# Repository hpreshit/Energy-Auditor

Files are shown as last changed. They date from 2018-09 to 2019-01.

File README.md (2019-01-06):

<p align="center">
 Energy Auditor Logo
</p>  

## Low Power Embedded Design Techniques Course Project - University of Colorado Boulder
## Team  
###  Gunj Manseta  |  Preshit Harlikar  
###  Aakash Kumar  |  Ashish Tak  |  Smitesh Modak  

## Project Idea  
We intend to build an Energy Auditing System through a combination of Bluetooth mesh
sensor nodes and a Gateway. The system will gather all the sensor node information and
send it to cloud for data analysis through Gateway.
Two Teams will collaborate to build this entire system. Our team will work on developing a
Bluetooth mesh network of wireless power meter sensor nodes that can clamp on to mains
line noninvasively. These nodes will report the measured power to the Gateway which will
be developed by the other team.

## What problem does the project solve?
Energy audit and conservation projects require measuring the existing power consumption
for the equipment under audit to create a baseline of the existing consumption. Electrical
circuits may not be isolated by the type of equipment in many buildings, this causes errors
in calculation of the power consumption of the equipment under audit, resulting in
erroneous calculation of the baseline, which in turns affects all other energy conservation
calculations. Setting up wired metering infrastructure for such temporary measurements
would be very tedious and labor intensive. Our project will help setup temporary metering
infrastructure that is not labor intensive to setup due to it being wireless and noninvasive.
  
## System Block Diagram
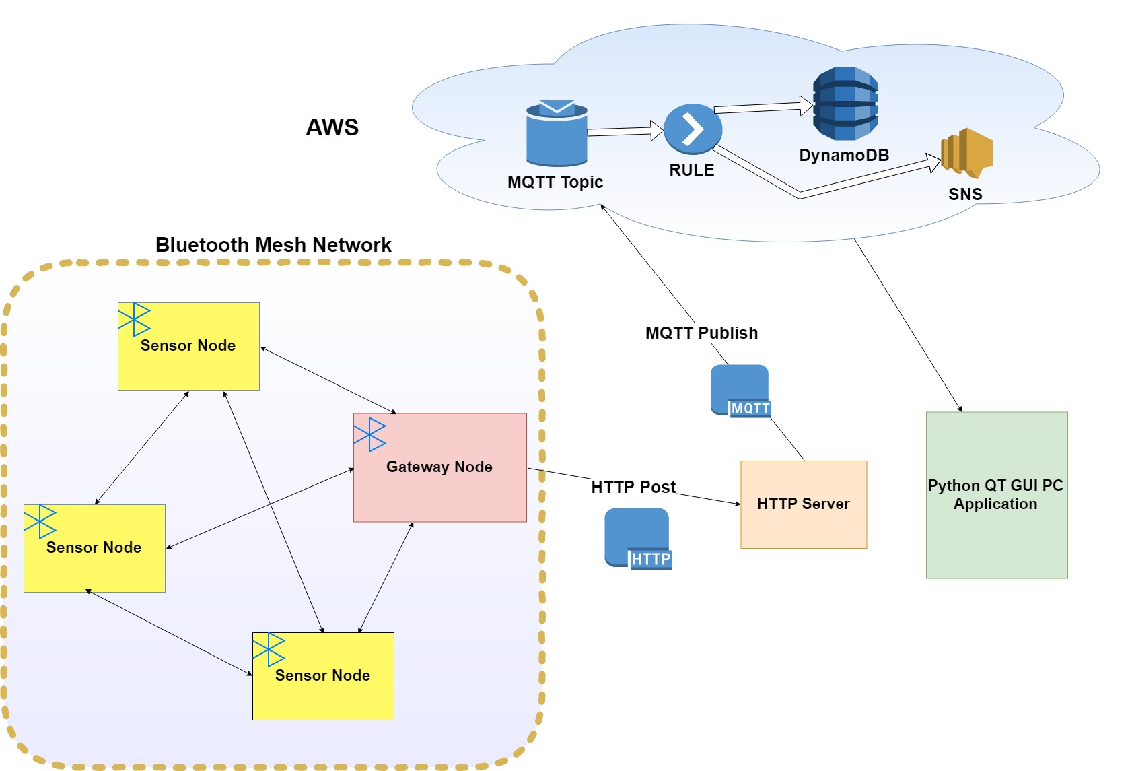
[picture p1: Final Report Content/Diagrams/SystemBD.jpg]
System Block Diagram


## Sensor Node Block Diagram
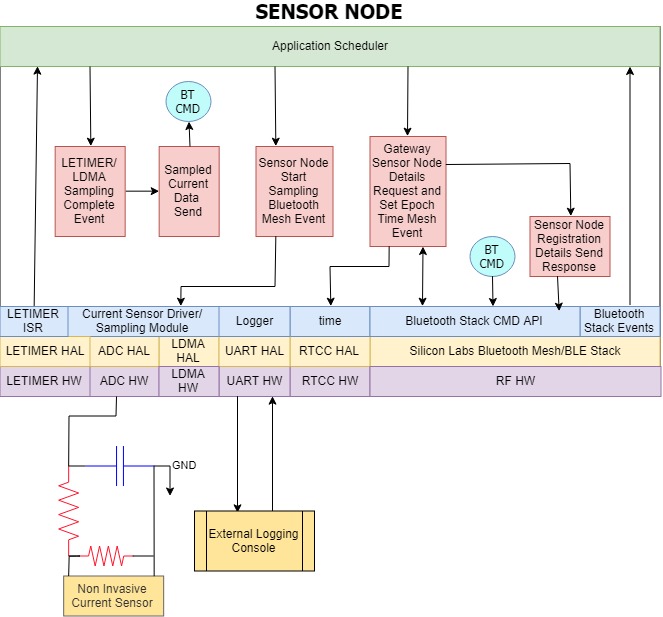
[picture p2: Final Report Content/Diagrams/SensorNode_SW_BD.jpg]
System Block Diagram


## Gateway Node Block Diagram
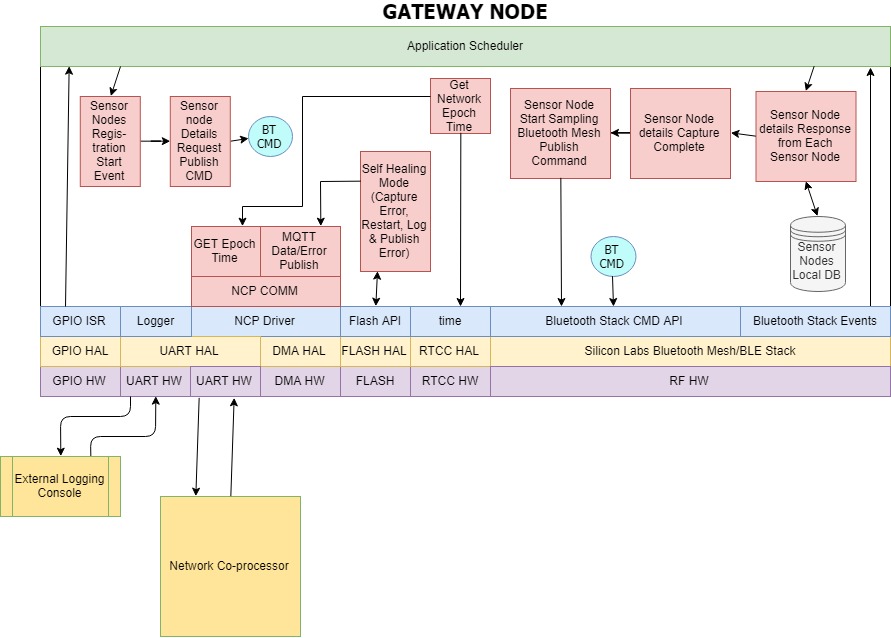
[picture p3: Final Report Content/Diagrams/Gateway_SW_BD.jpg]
System Block Diagram


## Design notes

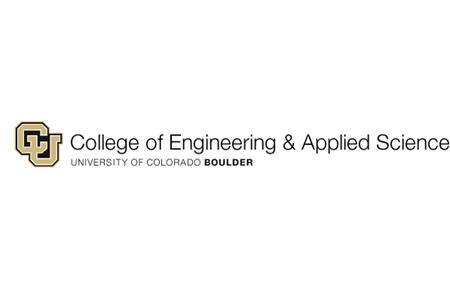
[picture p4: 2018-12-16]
PC Application/Images/cuengineering.png

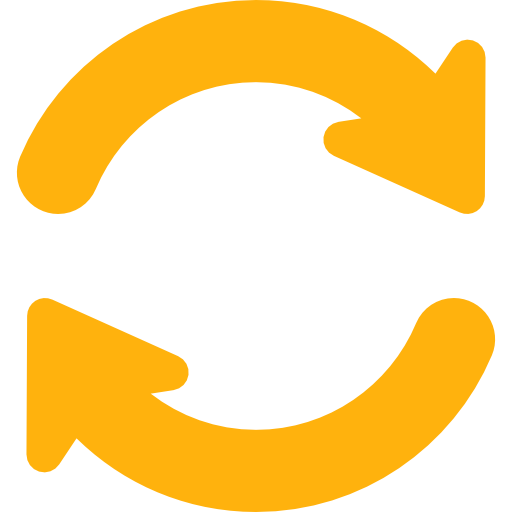
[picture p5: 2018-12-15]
PC Application/Images/refreshbutton.png

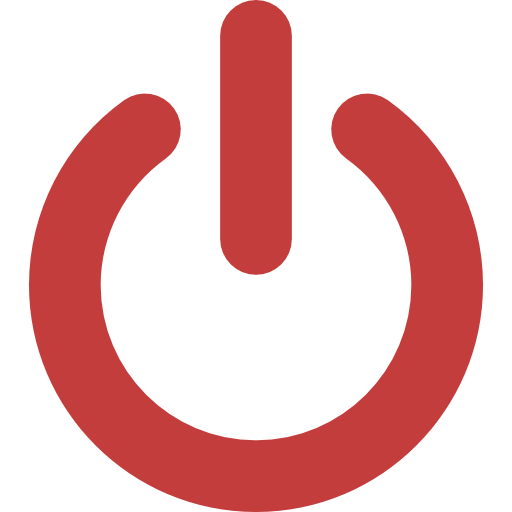
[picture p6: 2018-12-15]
PC Application/Images/powerbutton.png

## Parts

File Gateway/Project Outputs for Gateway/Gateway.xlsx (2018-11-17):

Description | Designator | Digi-Key Part Number | Manufacturer Part Number | Quantity | Value
CONN HEADER PH SIDE 2POS 2MM SMD | B1 | 455-1749-1-ND | S2B-PH-SM4-TB(LF)(SN) | 1
CAP CER 1UF 10V X7R 0603 | C1, C3, C7 | 1276-1946-1-ND | CL10B105KP8NNNC | 3 | 1uF
CAP CER 0.1UF 16V X7R 0603 | C11, C12 | 1276-1258-1-ND | CL10F104ZO8NNNC | 2 | 100nF
CAP CER 22UF 10V X5R 0603 | C2, C4, C6, C8, C13 | 1276-6504-1-ND | CL10A226MPCNUBE | 5 | 22uF
CAP CER 1300PF 25V C0G/NP0 0603 | C5 | 399-14953-1-ND | C0603C132J3GAC7867 | 1 | 1.3nF
CAP CER 1000PF 50V X7R 0603 | C9, C10 | 478-5006-1-ND | 06035C102JAT2A | 2 | 1nF
Blue 470nm LED Indication - Discrete 2.85V 0603 (1608 Metric) | D1 | 475-2816-1-ND | LB Q39G-L2OO-35-1 | 1
LED GREEN DIFFUSED 0603 SMD | D2 | 475-3118-1-ND | LG L29K-F2J1-24-Z | 1
LED RED DIFFUSED 0603 SMD | D23 | 475-1195-1-ND | LS L29K-H1J2-1-Z | 1
LED YELLOW DIFFUSED 0603 SMD | D24 | 475-1196-1-ND | LY L29K-H1K2-26-Z | 1
LED GREEN DIFFUSED 0603 SMD | D3 | 475-3118-1-ND | LG L29K-F2J1-24-Z | 1
DIODE ZENER 3.3V 125MW 0402 | D4, D8, D9, D10, D11, D12, D13, D14, D15, D16, D17, D18, D19, D20, D21, D22, D25, D26, D27, D28, D29 | 641-1682-1-ND | CZRQR3V3B-HF | 21
LED GREEN DIFFUSED 0603 SMD | D6 | 475-3118-1-ND | LG L29K-F2J1-24-Z | 1
LED GREEN DIFFUSED 0603 SMD | D7 | 475-3118-1-ND | LG L29K-F2J1-24-Z | 1
FIXED IND 1.5UH 1.1A 213 MOHM | L1 | 490-15637-1-ND | LQM18PN1R5MFHD | 1 | 1.5uH
Micro Usb, 2.0 Type Ab, Receptacle, Th | P1 | 609-4053-1-ND | 10104111-0001LF | 1
Header, 2-Pin | P2, P3 |  |  | 2
.050" X .050 TERMINAL STRIP | P4 | SAM13160CT-ND | FTSH-105-01-F-DV-K-TR | 1
Header, 10-Pin | P5 |  |  | 1
.025 SQ. TERMINAL STRIPS | P6 | SAM14883CT-ND | TSM-110-01-L-DH-A-P-TR | 1
PTC RESET FUSE 6V 500MA 1206 | R1 | F2112CT-ND | Littelfuse Inc. | 1
RES SMD 1M OHM 5% 1/10W 0603 | R16, R17 | 1276-5134-1-ND | RC1608J105CS | 2 | 1M
RES SMD 100 OHM 5% 1/10W 0603 | R18, R19, R22 | 541-4059-1-ND | CRCW0603100RJNEAC | 3 | 100R, 100R, 100
RES SMD 10K OHM 1% 1/8W 0603 | R2, R6 | MCT0603-10.0K-CFCT-ND | MCT06030C1002FP500 | 2 | 10K
RES 0 OHM JUMPER 1/8W 0603 | R3, R11, R25, R26 | 749-1745-1-ND | MCT0603MZ0000ZP500 | 4 | 0R
RES SMD 2.2K OHM 1% 1/10W 0603 | R4 | P2.20KHCT-ND | ERJ-3EKF2201V | 1 | 2.2K
RES SMD 3.3K OHM 5% 1/10W 0603 | R5, R9, R13, R20, R21 | P3.3KGCT-ND | ERJ-3GEYJ332V | 5 | 3.3K
RES SMD 100K OHM 0.1% 1/10W 0603 | R7, R10, R12 | RG16P100KBCT-ND | RG1608P-104-B-T5 | 3 | 100K
RES SMD 1K OHM 1% 1/8W 0603 | R8, R23, R24 | MCT0603-1.00K-CFCT-ND | MCT06030C1001FP500 | 3 | 1K
SWITCH SLIDE SPDT 100MA 12V | S1 | 401-2012-1-ND | AYZ0102AGRLC | 1
MHS22204=DPDT SL SW VERT AG | S2 | 450-1572-ND | 1825289-1 | 1
SWITCH TACTILE SPST-NO 0.05A 12V | S3, S4, S5 | 732-7004-1-ND | 430182043816 | 3
PC TEST POINT MINIATURE | TP1, TP2, TP3, TP5, TP6, TP10, TP11 | 36-5019CT-ND | 5019 | 7
IC LI-ION CHARGE MGMT 16-QFN | U1 | 296-38874-1-ND | BQ24075RGTT | 1
Tiny Single Inductor Buck Boost Converter 12-VQFN -40 to 85 | U2 | 296-42650-1-ND | TPS63051RMWR | 1
EFR32BG13 Bluetooth 5.0 Module, 512kB Flash, +8dbm | U3 | 336-5465-1-ND | BGM13P22F512GA-V2 | 1
USB Bridge, USB to UART USB 2.0 UART Interface 28-SSOP | U4 | 768-1007-1-ND | FT232RL-REEL | 1

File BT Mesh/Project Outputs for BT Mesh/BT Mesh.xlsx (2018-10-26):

Designator | Comment | Description | Value | Quantity | ComponentLink1Description | ComponentLInk1URL | Digi-Key Part Number | Mouser Part Number | Manufacturer | Manufacturer Part Number
B1 | S2B-PH-SM4-TB(LF)(SN) | PH Series 2 Position 2 mm Pitch Surface Mount Side Entry Shrouded Header |  | 1 | Digi-Key Link | https://www.digikey.com/products/en/connectors-interconnects/rectangular-connectors-headers-male-pins/314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 | 455-1749-1-ND |  | JST Sales America Inc. | S2B-PH-SM4-TB(LF)(SN)
B2 | SMTU2450N-LF_BULK | Coin Cell Battery Holders SFC MNT FOR CR2450N |  | 1 | Mouser Link | https://www.mouser.com/ProductDetail/Renata/SMTU2450N-LF-BULK?qs=LsPilcdHE7Gn4SDnejz9jQ%3D%3D |  | 614-SMTU2450N-LF | RENATA | SMTU2450N-LF BULK
C1, C3, C7, C8 | 1uF | CAP CER 1UF 16V X7R 0603 | 1uF | 4 | Digi-Key Link | https://www.digikey.com/product-detail/en/samsung-electro-mechanics/CL10B105MO8NNWC/1276-6524-1-ND/5961383 | 1276-6524-1-ND |  | Samsung Electro-Mechanics | CL10B105MO8NNWC
C2, C4, C6 | 10uF | CAP CER 10UF 10V X5R 0603 | 10uF | 3 | Digi-Key Link | https://www.digikey.com/products/en?keywords=490-10474-1-ND | 490-10474-1-ND |  | Murata Electronics North America | GRM188R61A106KE69D
C5 | 1.3nF | CAP CER 1300PF 25V C0G/NP0 0603 | 1.3nF | 1 | Digi-Key Link | https://www.digikey.com/product-detail/en/kemet/C0603C132J3GAC7867/399-14953-1-ND/7382502 | 399-14953-1-ND |  | KEMET | C0603C132J3GAC7867
C9, C10 | 1nF | CAP CER 1000PF 50V X7R 0603 | 1nF | 2 | Digi-Key Link | https://www.digikey.com/product-detail/en/avx-corporation/06035C102JAT2A/478-5006-1-ND/1888217 | 478-5006-1-ND |  | AVX Corporation | 06035C102JAT2A
C11, C12 | 100nF | CAP CER 0.1UF 16V X7R 0603 | 100nF | 2 | Digi-Key Link | https://www.digikey.com/products/en/capacitors/ceramic-capacitors/60?k=capacitor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 | 478-7617-1-ND |  | AVX Corporation | 0603YC104MAT4A
D1 | LED_CHG | Blue 470nm LED Indication - Discrete 2.85V 0603 (1608 Metric) |  | 1 | Digi-Key Link | https://www.digikey.com/product-detail/en/osram-opto-semiconductors-inc/LB-Q39G-L2OO-35-1/475-2816-1-ND/2176355 | 475-2816-1-ND |  | OSRAM Opto Semiconductors Inc. | LB Q39G-L2OO-35-1
D2 | LED_PG | LED GREEN DIFFUSED 0603 SMD |  | 1 | Digi-Key Link | https://www.digikey.com/product-detail/en/osram-opto-semiconductors-inc/LG-L29K-F2J1-24-Z/475-3118-1-ND/4899549 | 475-3118-1-ND |  | OSRAM Opto Semiconductors Inc. | LG L29K-F2J1-24-Z
D3 | LED_EXT | LED GREEN DIFFUSED 0603 SMD |  | 1 | Digi-Key Link | https://www.digikey.com/product-detail/en/osram-opto-semiconductors-inc/LG-L29K-F2J1-24-Z/475-3118-1-ND/4899549 | 475-3118-1-ND |  | OSRAM Opto Semiconductors Inc. | LG L29K-F2J1-24-Z
D4, D5, D8, D9, D10, D11, D12, D13, D14, D15, D16, D17, D18, D19, D20, D21, D22 | D Zener | TVS DIODE 5.5V 14V 2X1SON, Zener Diode, TVS DIODE 5.5V 14V 2X1SON, TVS DIODE 5.5V 14V 2X1SON, TVS DIODE 5.5V 14V 2X1SON, TVS DIODE 5.5V 14V 2X1SON, TVS DIODE 5.5V 14V 2X1SON, TVS DIODE 5.5V 14V 2X1SON, TVS DIODE 5.5V 14V 2X1SON, TVS DIODE 5.5V 14V 2X1SON, TVS DIODE 5.5V 14V 2X1SON, TVS DIODE 5.5V 14V 2X1SON, TVS DIODE 5.5V 14V 2X1SON, TVS DIODE 5.5V 14V 2X1SON, TVS DIODE 5.5V 14V 2X1SON, TVS DIODE 5.5V 14V 2X1SON, TVS DIODE 5.5V 14V 2X1SON |  | 17 | Digi-Key Link | https://www.digikey.com/product-detail/en/texas-instruments/TPD1E10B06DPYR/296-30406-1-ND/3283560 | 296-30406-1-ND |  | Texas Instruments | TPD1E10B06DPYR
D6 | LED0 | LED GREEN DIFFUSED 0603 SMD |  | 1 | Digi-Key Link | https://www.digikey.com/product-detail/en/osram-opto-semiconductors-inc/LG-L29K-F2J1-24-Z/475-3118-1-ND/4899549 | 475-3118-1-ND |  | OSRAM Opto Semiconductors Inc. | LG L29K-F2J1-24-Z
D7 | LED1 | LED GREEN DIFFUSED 0603 SMD |  | 1 | Digi-Key Link | https://www.digikey.com/product-detail/en/osram-opto-semiconductors-inc/LG-L29K-F2J1-24-Z/475-3118-1-ND/4899549 | 475-3118-1-ND |  | OSRAM Opto Semiconductors Inc. | LG L29K-F2J1-24-Z
D23 | LED_RX | LED RED DIFFUSED 0603 SMD |  | 1 | Digi-Key Link | https://www.digikey.com/product-detail/en/osram-opto-semiconductors-inc/LG-L29K-F2J1-24-Z/475-3118-1-ND/4899549 | 475-1195-1-ND |  | OSRAM Opto Semiconductors Inc. | LS L29K-H1J2-1-Z
D24 | LED_TX | LED YELLOW DIFFUSED 0603 SMD |  | 1 | Digi-Key Link | https://www.digikey.com/product-detail/en/osram-opto-semiconductors-inc/LY-L29K-H1K2-26-Z/475-1196-1-ND/810357 | 475-1196-1-ND |  | OSRAM Opto Semiconductors Inc. | LY L29K-H1K2-26-Z
J1 | SJ2-35043C-SMT-TR | AUDIO JACK, 3.5 MM, RT, 4 CONDUC |  | 1 | Digi-Key Link | https://www.digikey.com/products/en/connectors-interconnects/barrel-audio-connectors/434?k=SJ2-35043C-SMT-TR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 | CP-SJ2-35043C-SMT-CT-ND |  | CUI Inc. | SJ2-35043C-SMT-TR
L1 | 1.5uH | FIXED IND 1.5UH 1.1A 213 MOHM | 1.5uH | 1 | Digi-Key Link | https://www.digikey.com/product-detail/en/murata-electronics-north-america/LQM18PN1R5MFHD/490-15637-1-ND/6800302 | 490-15637-1-ND |  | Murata Electronics North America | LQM18PN1R5MFHD
P1 | 10104111-0001LF | Micro Usb, 2.0 Type Ab, Receptacle, Th |  | 1 | Digi-Key Link | https://www.digikey.com/product-detail/en/amphenol-fci/10104111-0001LF/609-4053-1-ND/2350359 | 609-4053-1-ND |  | Amphenol FCI | 10104111-0001LF
P2, P3 | Header 2 | Header, 2-Pin |  | 2
P4 | SAMTEC-FTSH-105-01-X-DV | .050" X .050 TERMINAL STRIP |  | 1 | Digi-Key Link | https://www.digikey.com/products/en/connectors-interconnects/rectangular-connectors-headers-male-pins/314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 | SAM13160CT-ND |  | Samtec | FTSH-105-01-F-DV-K-TR
P5 | Header 10 | Header, 10-Pin |  | 1
R1 | PTC FUSE | PTC RESET FUSE 6V 500MA 1206 |  | 1 | Digi-Key Link | https://www.digikey.com/product-detail/en/littelfuse-inc/1206L050YR/F2112CT-ND/455721 | F2112CT-ND |  | Bel Fuse | Littelfuse Inc.
R2, R6 | 10K | RES SMD 10K OHM 1% 1/8W 0603 | 10K | 2 | Digi-Key Link | https://www.digikey.com/products/en?keywords=MCT0603-10.0K-CFCT-ND | MCT0603-10.0K-CFCT-ND |  | Vishay Beyschlag | MCT06030C1002FP500
R3, R11, R25 | 0R | RES 0 OHM JUMPER 1/8W 0603 | 0R | 3 | Digi-Key Link | https://www.digikey.com/product-detail/en/vishay-beyschlag/MCT0603MZ0000ZP500/749-1745-1-ND/7348053 | 749-1745-1-ND |  | Vishay Beyschlag | MCT0603MZ0000ZP500
R4 | 8.9K | RES SMD 8.87KOHM 0.5% 1/10W 0603 | 8.9K | 1 | Digi-Key Link | https://www.digikey.com/product-detail/en/yageo/RT0603DRD078K87L/311-8.87KDCT-ND/1035893 | 311-8.87KDCT-ND |  | Yageo | RT0603DRD078K87L
R5, R9, R13, R20, R21 | 3.3K | RES SMD 3.3K OHM 5% 1/10W 0603 | 3.3K | 5 | Digi-Key Link | https://www.digikey.com/product-detail/en/panasonic-electronic-components/ERJ-3GEYJ332V/P3.3KGCT-ND/135146 | P3.3KGCT-ND |  | Panasonic Electronic Components | ERJ-3GEYJ332V
R7, R10, R12 | 100K | RES SMD 100K OHM 0.1% 1/10W 0603 | 100K | 3 | Digi-Key Link | https://www.digikey.com/products/en/resistors/chip-resistor-surface-mount/52?k=RG1608P-104-B-T5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 | RG16P100KBCT-ND |  | Susumu | RG1608P-104-B-T5
R8, R23, R24 | 1K | RES SMD 1K OHM 0.1% 1/10W 0603 | 1K | 3 | Digi-Key Link | https://www.digikey.com/product-detail/en/yageo/RT0603BRD071KL/YAG1237CT-ND/4340590 | YAG1237CT-ND |  | Yageo | RT0603BRD071KL
R14 | 330R | RES SMD 330 OHM 5% 1/10W 0603 | 330 | 1 | Digi-Key Link | https://www.digikey.com/product-detail/en/vishay-dale/CRCW0603330RJNEAC/541-4060-1-ND/7928743 | 541-4060-1-ND |  | Vishay Dale | CRCW0603330RJNEAC
R15 | 1.6K | RES SMD 1.6K OHM 5% 1/10W 0603 | 1.6K | 1 | Digi-Key Link | https://www.digikey.com/product-detail/en/yageo/RC0603JR-071K6L/311-1.6KGRCT-ND/729639 | 311-1.6KGRCT-ND |  | Yageo | RC0603JR-071K6L
R16, R17 | 1M | RES SMD 1M OHM 5% 1/10W 0603 | 1M | 2 | Digi-Key Link | https://www.digikey.com/product-detail/en/samsung-electro-mechanics/RC1608J105CS/1276-5134-1-ND/3968106 | 1276-5134-1-ND |  | Samsung Electro-Mechanics | RC1608J105CS
R18, R19, R22 | 100R | RES SMD 100 OHM 5% 1/10W 0603 | 100R | 3 | Digi-Key Link | https://www.digikey.com/product-detail/en/vishay-dale/CRCW0603100RJNEAC/541-4059-1-ND/7928742 | 541-4059-1-ND |  | Vishay Dale | CRCW0603100RJNEAC
S1 | AYZ0102AGRLC | SWITCH SLIDE SPDT 100MA 12V |  | 1 | Digi-Key Link | https://www.digikey.com/products/en/switches/slide-switches/213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 | 401-2012-1-ND |  | C&K | AYZ0102AGRLC
S2 | 1825289-1 | MHS22204=DPDT SL SW VERT AG |  | 1 | Digi-Key Link | https://www.digikey.com/products/en?keywords=MHS22204 | 450-1572-ND |  | TE Connectivity | 1825289-1
S3 | PB0 | SWITCH TACTILE SPST-NO 0.05A 12V |  | 1 | Digi-Key Link | https://www.digikey.com/products/en/switches/tactile-switches/197?k=430+182+043+816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 | 732-7004-1-ND |  | Wurth Electronics | 430182043816
S4 | PB1 | SWITCH TACTILE SPST-NO 0.05A 12V |  | 1 | Digi-Key Link | https://www.digikey.com/products/en/switches/tactile-switches/197?k=430+182+043+816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 | 732-7004-1-ND |  | Wurth Electronics | 430182043816
S5 | RESET | SWITCH TACTILE SPST-NO 0.05A 12V |  | 1 | Digi-Key Link | https://www.digikey.com/products/en/switches/tactile-switches/197?k=430+182+043+816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 | 732-7004-1-ND |  | Wurth Electronics | 430182043816
TP1, TP2, TP3, TP4, TP10, TP11, TP12 | 5019 | Phosphor Bronze Contact Miniature Silver Plated Surface Mount Test Points |  | 7 | Digi-Key Link | https://www.digikey.com/product-detail/en/keystone-electronics/5019/36-5019CT-ND/3907344 | 36-5019CT-ND |  | Keystone | 5019
U1 | BQ24075 | IC LI-ION CHARGE MGMT 16-QFN |  | 1 | Digi-Key Link | https://www.digikey.com/products/en/integrated-circuits-ics/pmic-battery-chargers/781?k=BQ24075RGTR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 | 296-38874-1-ND |  | Texas Instruments | BQ24075RGTR
U2 | TPS63051RMWR | Tiny Single Inductor Buck Boost Converter 12-VQFN -40 to 85 |  | 1 | Digi-Key Link | https://www.digikey.com/products/en/integrated-circuits-ics/pmic-voltage-regulators-dc-dc-switching-regulators/739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 | 296-42650-1-ND |  | Texas Instruments | TPS63051RMWR
U3 | BGM13P22F512GA-V2 | BLUETOOTH 5.0 MODULE |  | 1 | Digi-Key Link | https://www.digikey.com/products/en/rf-if-and-rfid/rf-transceiver-modules/872?k=BGM13P22F512GA-V2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 | 336-5146-1-ND |  | Silicon Labs | BGM13P22F512GA-V2
U4 | FT232RL | USB Bridge, USB to UART USB 2.0 UART Interface 28-SSOP |  | 1 | Digi-Key Link | https://www.digikey.com/product-detail/en/ftdi-future-technology-devices-international-ltd/FT232RL-REEL/768-1007-1-ND/1836402 | 768-1007-1-ND |  | FTDI, Future Technology Devices International Ltd | FT232RL-REEL

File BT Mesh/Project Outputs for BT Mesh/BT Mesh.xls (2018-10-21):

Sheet: BOM Report
Bill of Materials |  |  | Blue Gecko
Source Data From: |  | BT Mesh.PrjPcb
Project: |  | BT Mesh.PrjPcb
Variant: |  | None
Creation Date: | 10/20/2018 | 6:46:58 PM
Print Date: | 2018-10-20 | 18:47:10
#Column Name Error:Footprint | Comment | #Column Name Error:LibRef | Designator | Description | Quantity
 | SMTU2450N-LF_BULK |  | B1 | Coin Cell Battery Holders SFC MNT FOR CR2450N | 1
 | 1uF |  | C1, C6, C10, C16, C17 | CAP CER 0.1UF 25V X7R 0603, CAP CER 1UF 16V X7R 0603, CAP CER 1UF 25V X5R 0603, CAP CER 1UF 25V X5R 0603, CAP CER 1UF 25V X5R 0603 | 5
 | 10uF |  | C2, C3, C5, C8, C15 | CAP CER 10UF 25V X5R 1206, CAP CER 10UF 6.3V X5R 0603, CAP CER 10UF 6.3V X5R 0603, CAP CER 10UF 6.3V X5R 0603, CAP CER 10UF 6.3V X5R 0603 | 5
 | 1.3nF |  | C4 | CAP CER 1300PF 25V C0G/NP0 0603 | 1
 | 10nF |  | C7 | Capacitor | 1
 | 100nF |  | C9 | CAP CER 0.1UF 16V X7R 0603 | 1
 | 10pF |  | C11, C13 | CAP CER 10PF 50V C0G/NP0 0603 | 2
 | 220nF |  | C12 | CAP CER 0.22UF 16V X7R 0603 | 1
 | 100pF |  | C14 | CAP CER 0.1UF 16V X7R 0603 | 1
 | 4.7uF |  | C18 | CAP CER 4.7UF 16V X5R 0603 | 1
 | 1.5pF |  | C19 | CAP CER 1.5PF 50V C0G/NP0 0402 | 1
 | 1nF |  | C20, C21 | CAP CER 1000PF 50V X7R 0603 | 2
 | LED_CHG |  | D1 | Blue 470nm LED Indication - Discrete 2.85V 0603 (1608 Metric) | 1
 | LED_PG |  | D2 | LED GREEN DIFFUSED 0603 SMD | 1
 | LED_EXT |  | D3 | LED GREEN DIFFUSED 0603 SMD | 1
 | D Zener |  | D4, D7, D8, D9, D10, D11, D12, D13, D14, D15, D16, D17, D18, D19, D20, D21, D22 | Zener Diode | 17
 | LED0 |  | D5 | LED GREEN DIFFUSED 0603 SMD | 1
 | LED1 |  | D6 | LED GREEN DIFFUSED 0603 SMD | 1
 | Antenna |  | E1 | Generic Antenna | 1
 | SJ2-35043C-SMT-TR |  | J1 | AUDIO JACK, 3.5 MM, RT, 4 CONDUC | 1
 | U.FL |  | J2 | U.FL Series 6 Ghz 50 Ohm Ultra-small SMT Coaxial Cable Receptacle | 1
 | 1.5uH |  | L1 | FIXED IND 1.5UH 1.1A 213 MOHM | 1
 | CBF102WB |  | L2 | FERRITE BEAD 1 KOHM 0603 1LN | 1
 | BLM18AG601SN1 |  | L3, L4 | FERRITE BEAD 600 OHM 0603 1LN | 2
 | 4.7uH |  | L5 | FIXED IND 4.7UH 500MA 500 MOHM | 1
 | 1.9nH |  | L6, L7 | FIXED IND 1.9NH 220MA 300 MOHM | 2
 | 0475901001 |  | P1 | Conn Micro USB Type AB RCP 5 POS 0.65mm Solder RA SMD 5 Terminal 1 Port Embossed T/R | 1
 | Header 2 |  | P2, P3 | Header, 2-Pin | 2
 | Header 6 |  | P4 | Header, 6-Pin | 1
 | Header 10 |  | P5 | Header, 10-Pin | 1
 | 10K |  | R1, R8 | RES SMD 10K OHM 1% 1/8W 0603 | 2
 | 8.9K |  | R2 | RES SMD 8.87KOHM 0.5% 1/10W 0603 | 1
 | 3.3K |  | R3, R6, R13, R18, R19 | RES SMD 3.3K OHM 5% 1/10W 0603 | 5
 | 100K |  | R4, R9, R10 | RES SMD 3.3K OHM 5% 1/10W 0603, RES SMD 3.3K OHM 5% 1/10W 0603, RES SMD 100K OHM 0.1% 1/10W 0603 | 3
 | 1K |  | R5 | RES SMD 1K OHM 0.1% 1/10W 0603 | 1
 | 0R |  | R7, R16, R17, R24 | RES 0 OHM JUMPER 1/8W 0603 | 4
 | 330 |  | R11 | RES SMD 330 OHM 5% 1/10W 0603 | 1
 | 1.6K |  | R12 | RES SMD 1.6K OHM 5% 1/10W 0603 | 1
 | 100R |  | R14, R22, R23 | RES SMD 100 OHM 5% 1/10W 0603 | 3
 | 1R |  | R15 | RES SMD 1 OHM 1% 1/16W 0402 | 1
 | 1M |  | R20, R21 | RES SMD 1M OHM 5% 1/10W 0603 | 2
 | AYZ0102AGRLC |  | S1 | SWITCH SLIDE SPDT 100MA 12V | 1
 | 1825289-1 |  | S2 | MHS22204=DPDT SL SW VERT AG | 1
 | 430182043816 |  | S3 | SWITCH TACTILE SPST-NO 0.05A 12V | 1
 | PB0 |  | S4 | SWITCH TACTILE SPST-NO 0.05A 12V | 1
 | PB1 |  | S5 | SWITCH TACTILE SPST-NO 0.05A 12V | 1
 | 5019 |  | TP1, TP2, TP3, TP4, TP5, TP6, TP10, TP11, TP12, TP13 | Phosphor Bronze Contact Miniature Silver Plated Surface Mount Test Points | 10
 | BQ24075 |  | U1 | IC LI-ION CHARGE MGMT 16-QFN | 1
 | TPS63051RMWR |  | U2 | Tiny Single Inductor Buck Boost Converter 12-VQFN -40 to 85 | 1
 | EFR32BG13P733F512GM48-B |  | U3 | EFR32BG13 Blue Gecko BluetoothÂ® Low Energy SoC | 1
 | 38.4MHz |  | X1 | Crystal 38.4mhz 8pf Smd | 1
 | 32.768KHz |  | X2 | CRYSTAL 32.768KHZ 12.5PF SMD | 1
 |  |  |  |  | 103
Approved |  | Notes

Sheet: Project Information
Project Full Path | C:\Users\Preshit\Documents\GitHub\Low-Power-Embedded-Design\BT Mesh\BT Mesh.PrjPcb
Project Filename | BT Mesh.PrjPcb
Variant Name | None
Data-Source Filename | BT Mesh.PrjPcb
Data-Source Full Path | C:\Users\Preshit\Documents\GitHub\Low-Power-Embedded-Design\BT Mesh\BT Mesh.PrjPcb
Title | Blue Gecko
Total Quantity | 103
Report Time | 6:46:58 PM
Report Date | 10/20/2018
Report Date & Tine | 10/20/2018 6:46:58 PM
Output Name | Bill of Materials
Output Type | BOM_PartType
Output Generator Name | BOM
Output Generator Description | Bill of Materials

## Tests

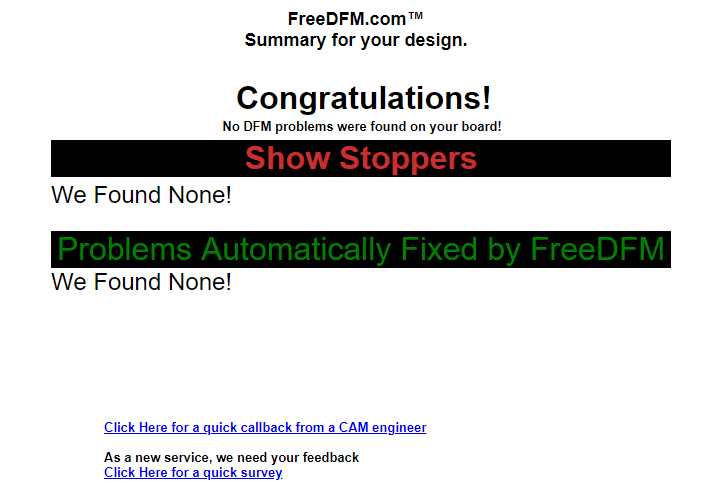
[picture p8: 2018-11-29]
BT Mesh/DFM Result.PNG

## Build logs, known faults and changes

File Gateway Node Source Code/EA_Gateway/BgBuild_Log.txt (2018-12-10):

// Copyright 2018 Silicon Laboratories, Inc.
//
//

Executing: bgbuild.exe (D:\SiliconLabs\SimplicityStudio\v4\developer\sdks\blemesh\v1.3\protocol\bluetooth\bin\bgbuild.exe)
Standard output
ALL OK

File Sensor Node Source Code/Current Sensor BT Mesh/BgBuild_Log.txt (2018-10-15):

// Copyright 2018 Silicon Laboratories, Inc.
//
//

Executing: bgbuild.exe (D:\SiliconLabs\SimplicityStudio\v4\developer\sdks\gecko_sdk_suite\v2.3\protocol\bluetooth\bin\bgbuild.exe)
Standard output
ALL OK

Error/Warning output
WARNING: 2a00 length attribute is 15 but actual value length is 14. 15 will be used.
WARNING: b5767a5fdfab4a87a1c1617f78278b16 length attribute is 4 but actual value length is 1. 4 will be used.

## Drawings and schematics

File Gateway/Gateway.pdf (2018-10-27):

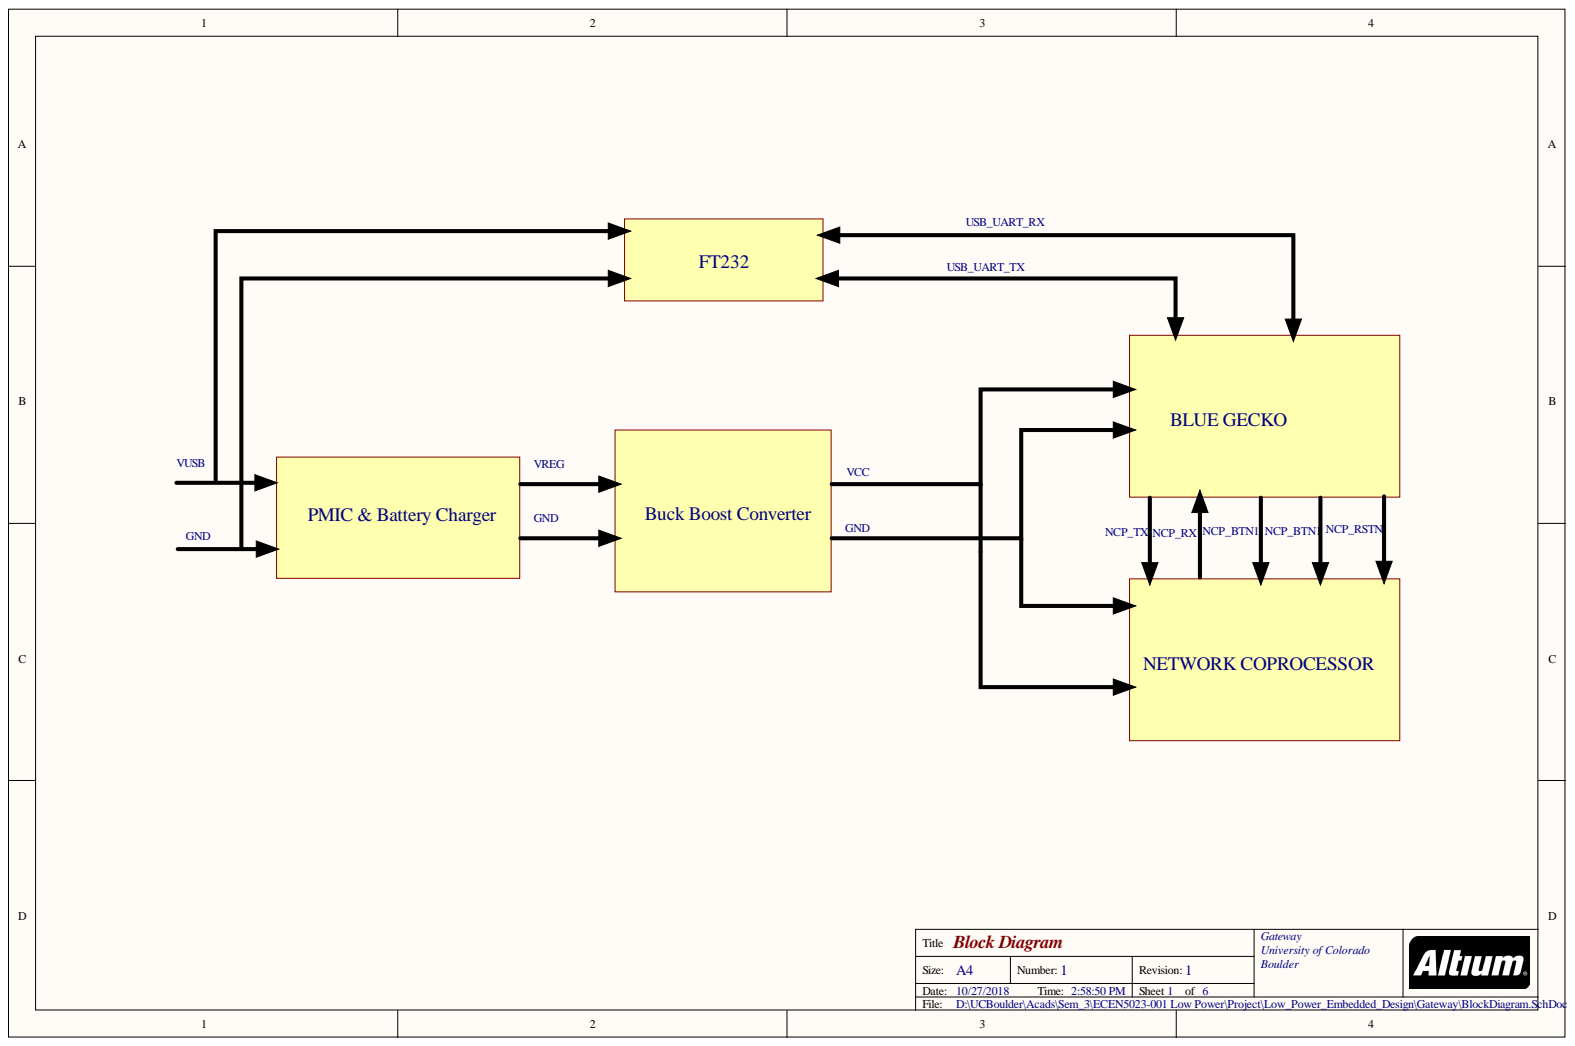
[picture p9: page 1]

Block Diagram Title | Gateway University of Colorado Boulder

A4 Size: | 1 Number: | 1 Revision:

Date: 10/27/2018 Time: 2:58:50 PM | | Sheet 1 of 6
File:

D:\UCBoulder\Acads\Sem_3\ECEN5023-001 Low Power\Project\Low_Power_Embedded_Design\Gateway\BlockDiagram.SchDoc

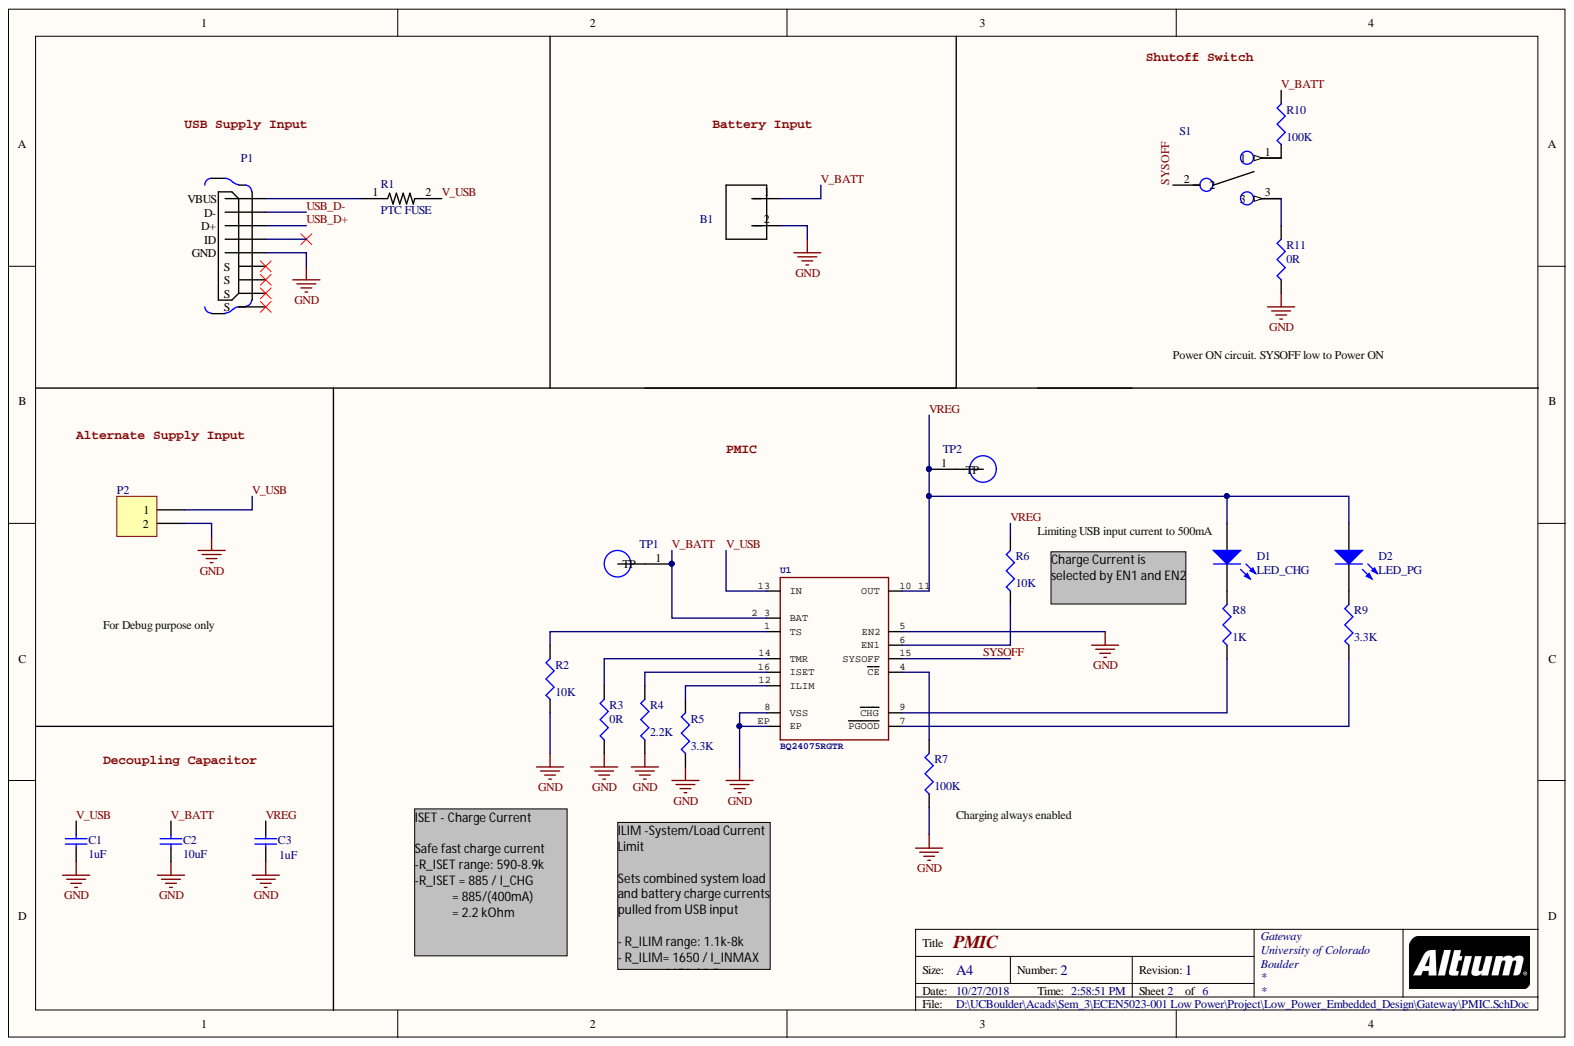
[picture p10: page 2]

1 | 6 | 4 GND

PMIC Titl e | Gatew ay University of Colo r a do Bo ulder * *

A4 S i ze: | 2 Nu mber : | 1 Rev i s i o n :

1 0/2 7/2 0 1 8 Ti me: 2 : 5 8 : 5 1 PM | | Sheet 2 o f 6
D :\U C B o u l d er\Acad s\Sem_ 3\ECEN 5 0 2 3 -0 0 1 Lo w Po wer\Project\Lo w_Po wer_Embed ded_ Des | i gn\Gateway\PM I C . Sch D o c

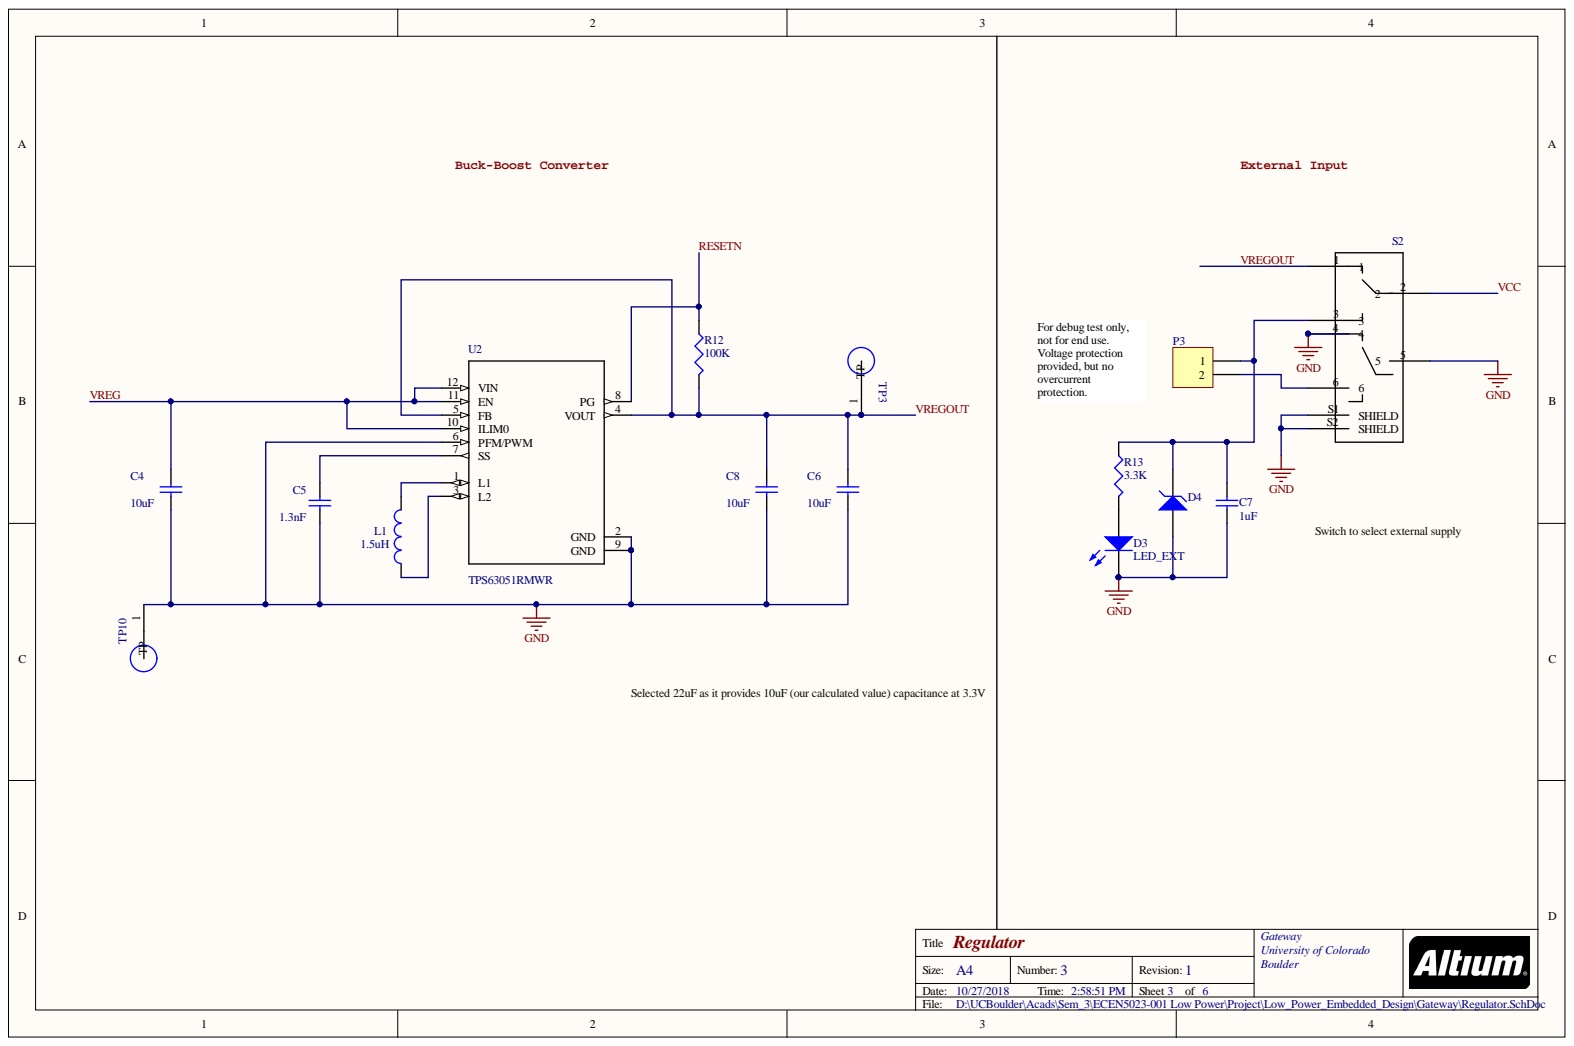
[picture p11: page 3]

itch to select exter

R eg u la to r Titl e | Gatew ay University of Colo r a do Bo ulder

A4 S i ze: | 3 Nu mber : | 1 Rev i s i o n :

1 0/2 7/2 0 1 8 Ti me: 2 : 5 8 : 5 1 PM | | Sheet 3 o f 6
D :\U C B o u l d er\Acad s\Sem_ 3\ECEN 5 0 2 3 -0 0 1 Lo w Po wer\Project\Lo w_Po wer_Embed ded_ Des | i gn\Gateway\Reg u lato r.Sch D | o

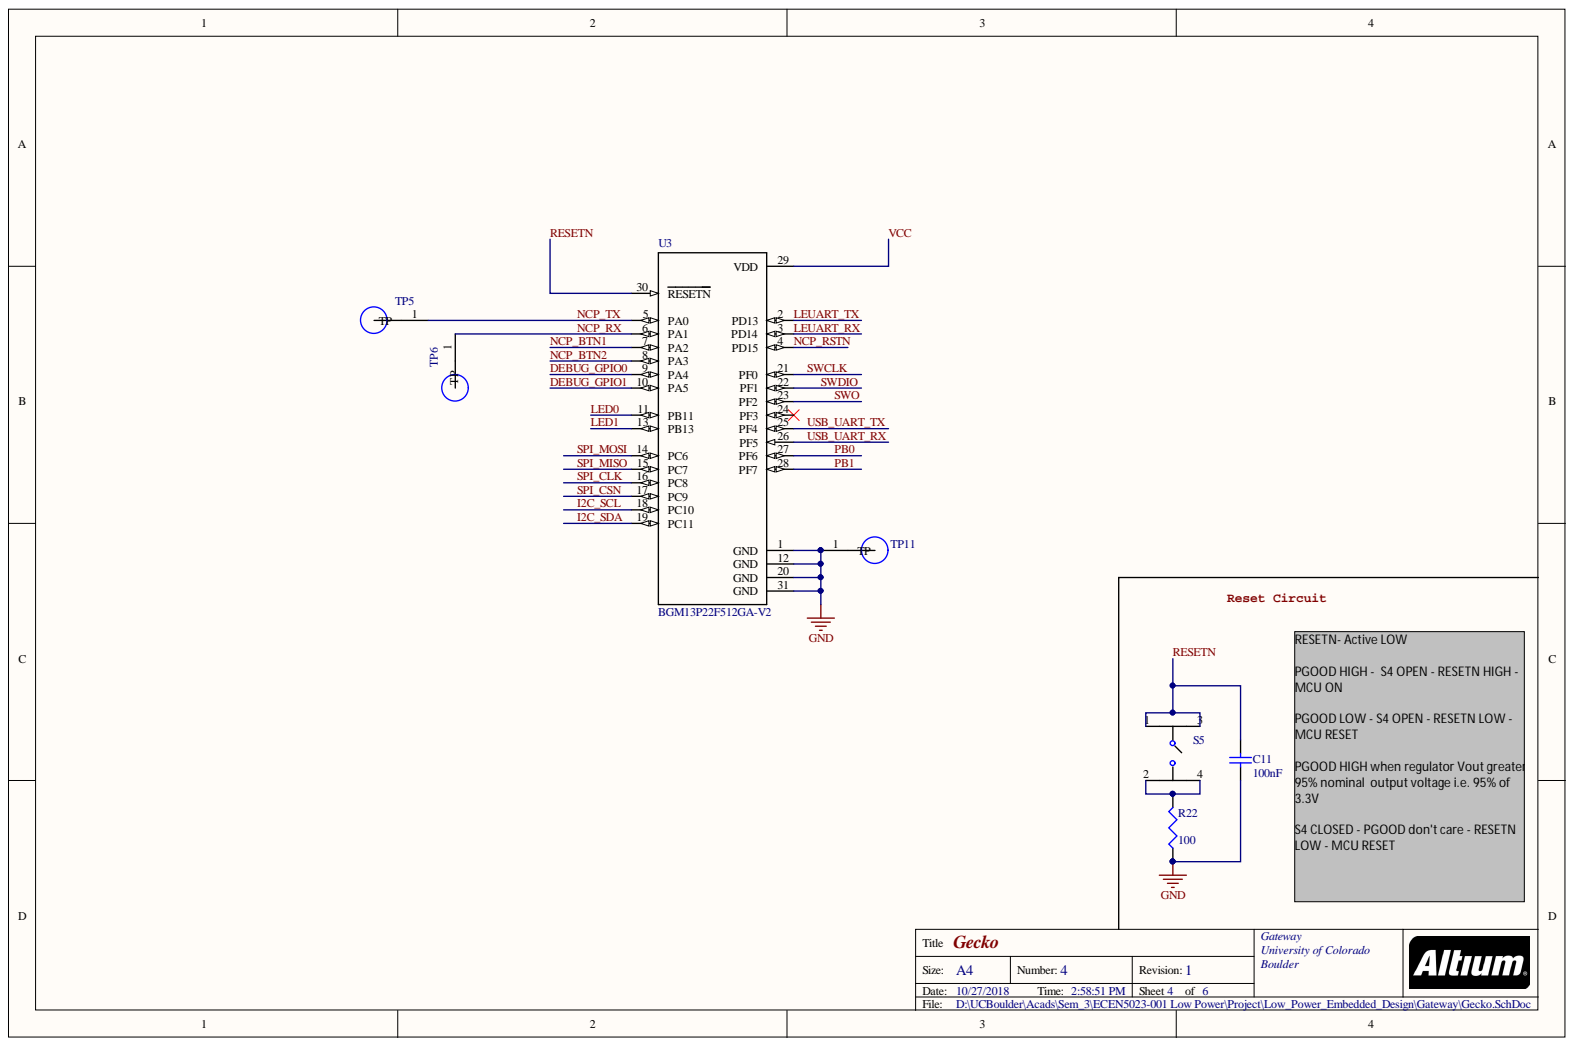
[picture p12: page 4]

Ge c ko Titl e | Gatew ay University of Colo r a do Bo ulder

A4 S i ze: | 4 Nu mber : | 1 Rev i s i o n :

1 0/2 7/2 0 1 8 Ti me: 2 : 5 8 : 5 1 PM | | Sheet 4 o f 6
D :\U C B o u l d er\Acad s\Sem_ 3\ECEN 5 0 2 3 -0 0 1 Lo w Po wer\Project\Lo w_Po wer_Embed ded_ Des | i gn\Gateway\Geck o . Sch D o c

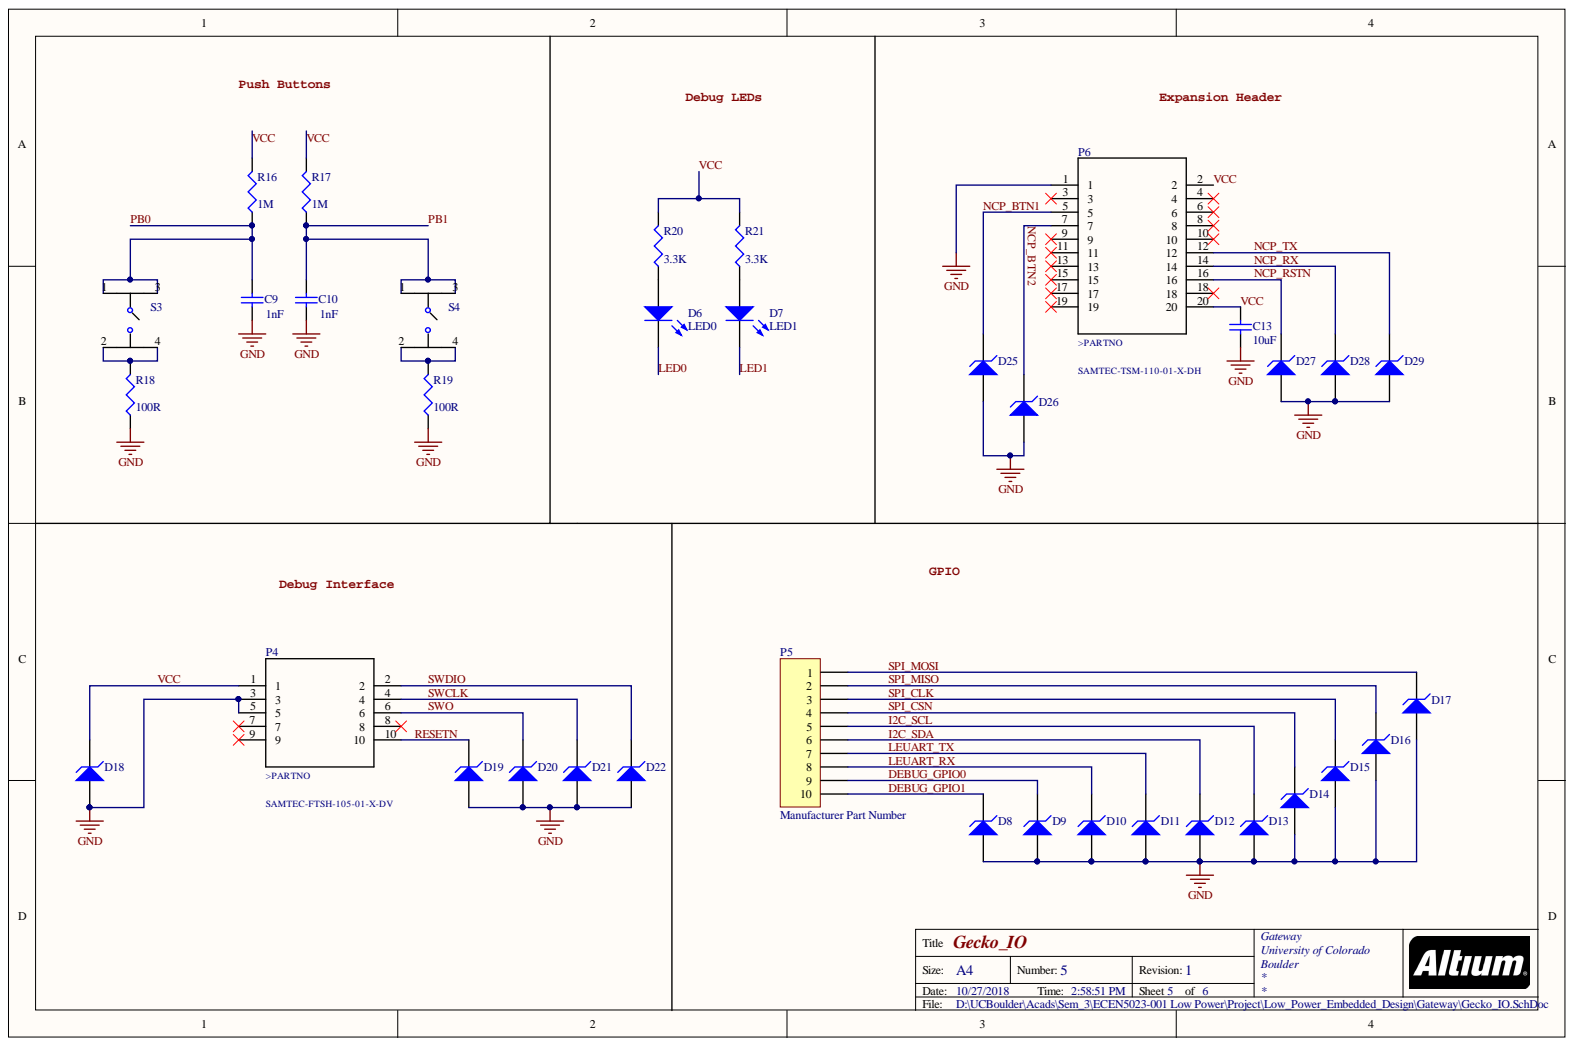
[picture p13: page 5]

NCP_RX
NCP_RSTN

LEUART_RX
DEBUG_GPIO0
DEBUG_GPIO1

Gecko_IO Title | Gateway University of Colorado Boulder * *

A4 Size: | 5 Number: | 1 Revision:

Date: 10/27/2018 Time: 2:58:51 PM | | Sheet 5 of 6
File:

D:\UCBoulder\Acads\Sem_3\ECEN5023-001 Low Power\Project\Low_Power_Embedded_Design\Gateway\Gecko_IO.SchDoc

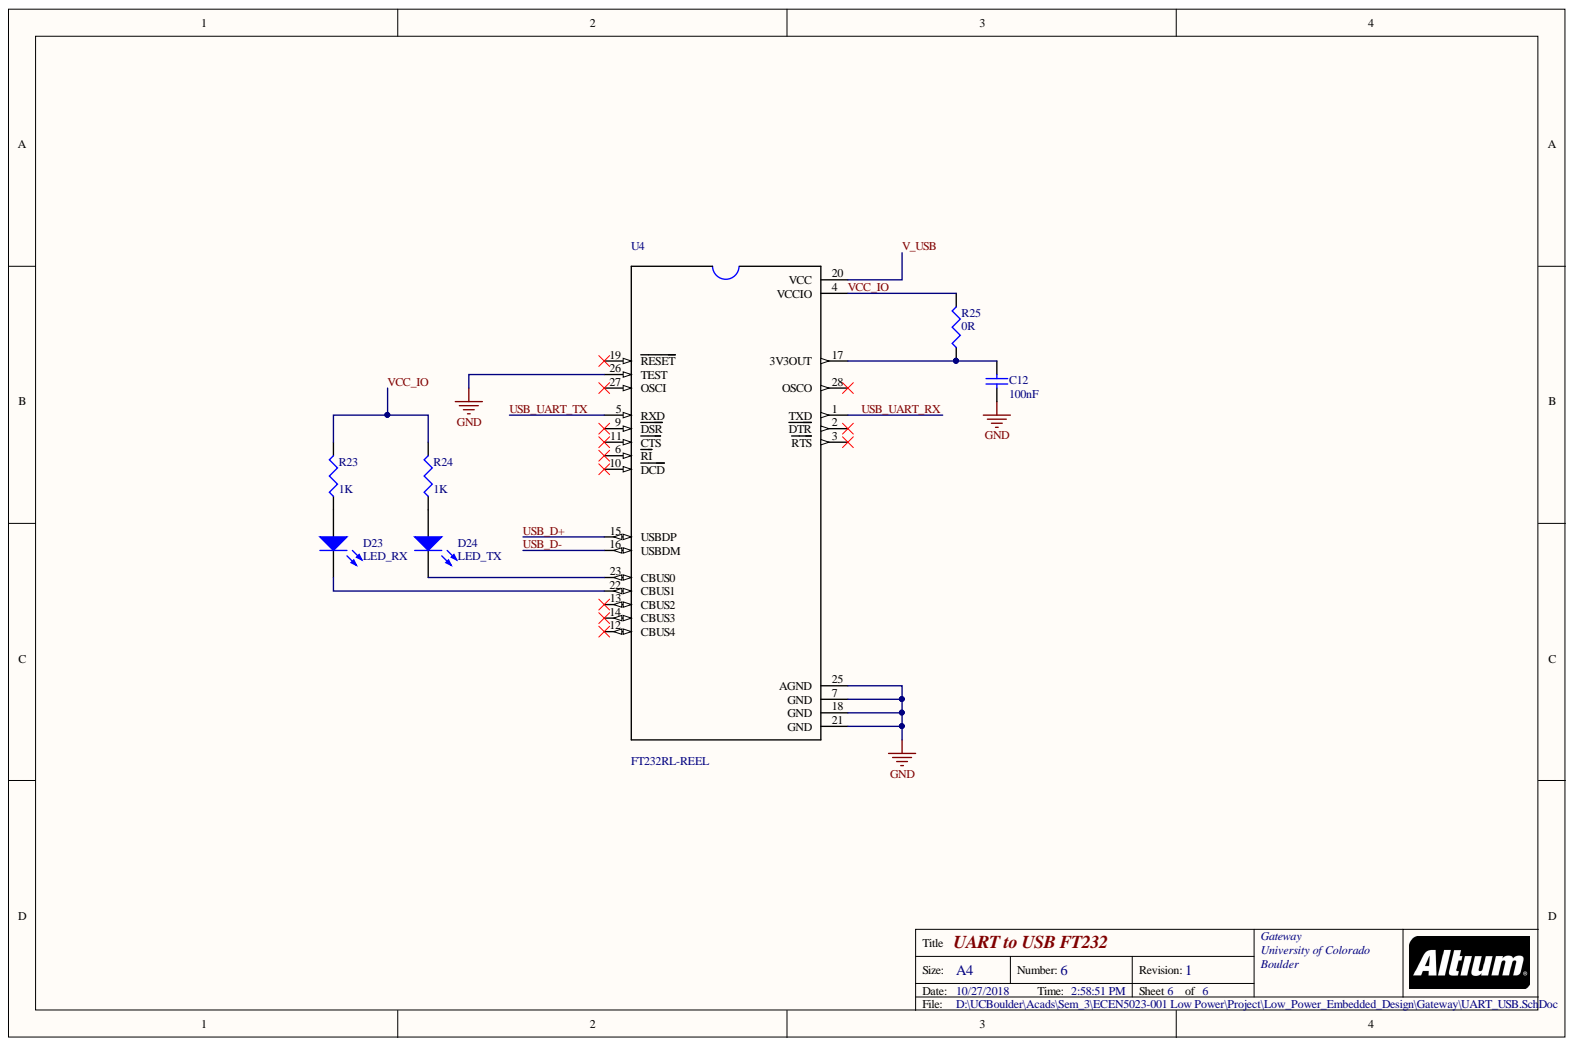
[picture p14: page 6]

UART to USB FT232 Title | Gateway University of Colorado Boulder

A4 Size: | 6 Number: | 1 Revision:

Date: 10/27/2018 Time: 2:58:51 PM | | Sheet 6 of 6
File:

D:\UCBoulder\Acads\Sem_3\ECEN5023-001 Low Power\Project\Low_Power_Embedded_Design\Gateway\UART_USB.SchDoc

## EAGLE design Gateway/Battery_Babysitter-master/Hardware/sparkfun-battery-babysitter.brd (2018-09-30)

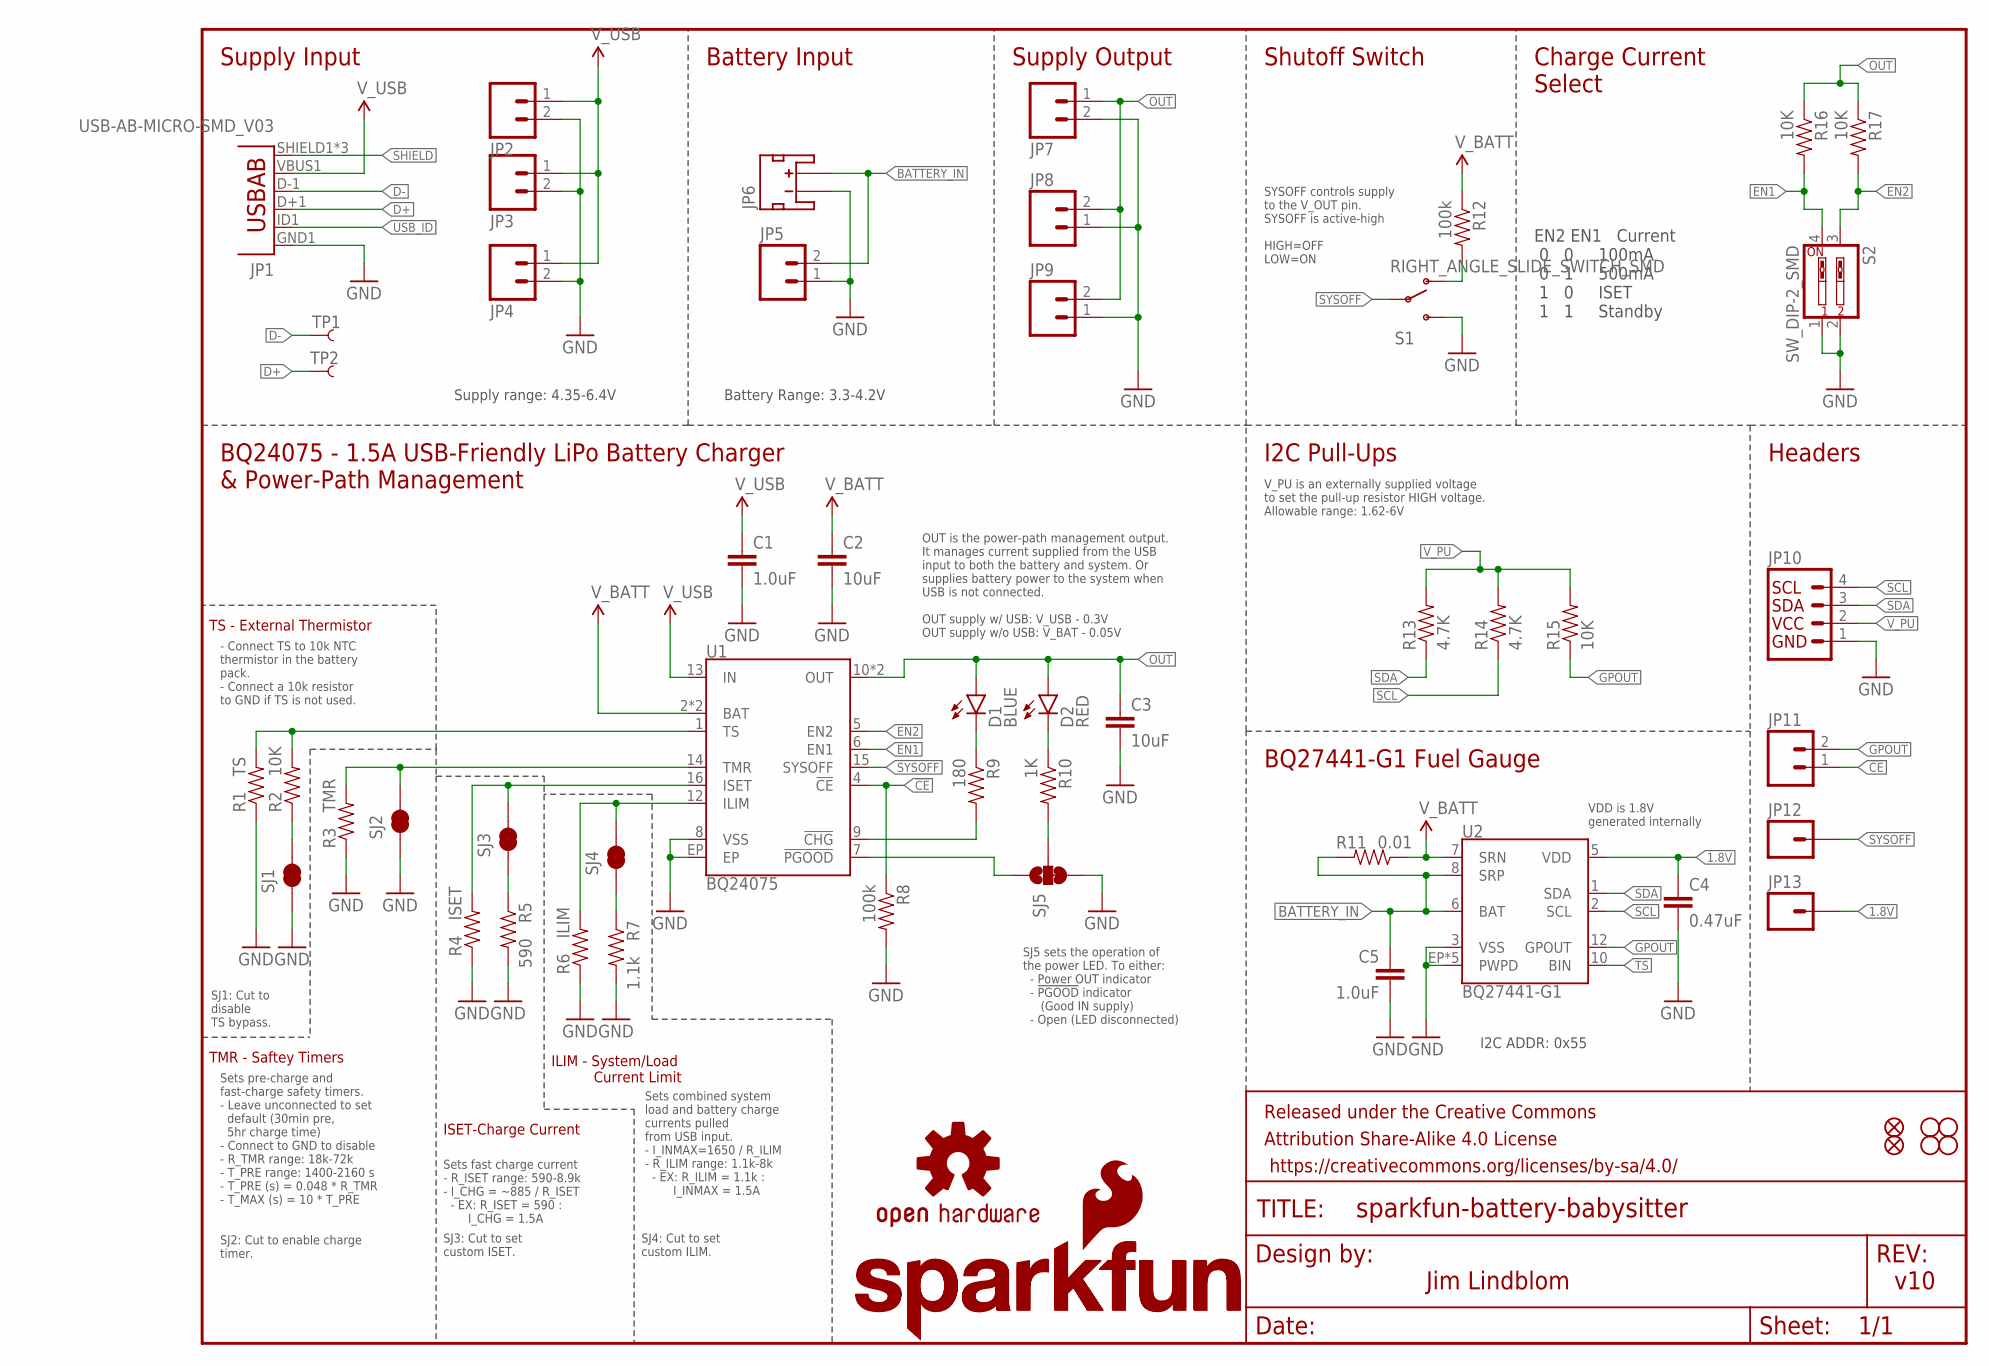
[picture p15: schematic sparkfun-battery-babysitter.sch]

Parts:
C1: 1.0uF; 1206-CAP
C2, C3: 10uF; 0805-CAP
C4: 0.47uF; 0603-CAP
C5: 1.0uF; 0603-CAP
D1: BLUE; LED-0603
D2: RED; LED-0603
FID1, FID2: FIDUCIAL1X2; FIDUCIAL-1X2
FRAME1: FRAME-LETTER; CREATIVE_COMMONS
JP1: USB-AB-MICRO-SMD_V03
JP2, JP4, JP5, JP8, JP11: M021X02_NO_SILK; 1X02_NO_SILK
JP3, JP7: M023.5MM-NO_SILK; SCREWTERMINAL-3.5MM-2-NS
JP6: JST_2MM_MALE; JST-2-SMD
JP9: M02-JST-2-PTH-NO_SILK; JST-2-PTH-NS
JP10: I2C_STANDARD_NO_SILK; 1X04_NO_SILK
JP12, JP13: M01PTH_NO_SILK_YES_STOP; 1X01_NO_SILK
LOGO1: SFE_LOGO_NAME.1_INCH; SFE_LOGO_NAME_.1
LOGO2: SFE_LOGO_NAME_FLAME.1_INCH; SFE_LOGO_NAME_FLAME_.1
LOGO3: OSHW-LOGOS; OSHW-LOGO-S
R1: TS; 1/6W-RES
R2, R15, R16, R17: 10K; 0603-RES
R3: TMR; 1/6W-RES
R4: ISET; 1/6W-RES
R5: 590; 0603-RES
R6: ILIM; 1/6W-RES
R7: 1.1k; 0603-RES
R8, R12: 100k; 0603-RES
R9: 180; 0603-RES
R10: 1K; 0603-RES
R11: 0.01; 1206
R13, R14: 4.7K; 0603-RES
S1: RIGHT_ANGLE_SLIDE_SWITCH_SMD; SWITCH-SPST-SMD-A
S2: SW_DIP-2_SMD; DIPSWITCH-02-50MIL
SJ1, SJ2, SJ3, SJ4: JUMPER-PAD-2-NC_BY_TRACE; PAD-JUMPER-2-NC_BY_TRACE_YES_SILK
SJ5: JUMPER-PAD-3-2OF3_NC_BY_TRACE_SMALL; PAD-JUMPER-3-2OF3_NC_BY_TRACE_YES_SILK_FULL_BOX
STANDOFF1, STANDOFF2, STANDOFF3, STANDOFF4: STAND-OFF
TP1, TP2: TEST-POINT3X4; PAD.03X.04
U1: BQ24075; PVQFN-N16
U2: BQ27441-G1; PDSO-N12

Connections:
1.8V: C4.1, JP13.1, U2.5 (VDD)
!CE!: JP11.1, R8.1, U1.4 (!CE!)
!CHG!: R9.2, U1.9 (!CHG!)
!PGOOD!: SJ5.1, U1.7 (!PGOOD!)
BATTERY_IN: C5.1, JP5.2, JP6.2 (+), R11.2, U2.6 (BAT), U2.8 (SRP)
D+: JP1.D+1 (D+), TP2.P$1
D-: JP1.D-1 (D-), TP1.P$1
EN1: R16.2, S2.4, U1.6 (EN1)
EN2: R17.2, S2.3, U1.5 (EN2)
GND: C1.2, C2.2, C3.2, C4.2, C5.2, JP1.GND1 (GND), JP2.2, JP3.2, JP4.2, JP5.1, JP6.1 (-), JP7.2, JP8.1, JP9.1, JP10.1, R1.1, R3.1, R4.1, R5.2, R6.1, R7.2, R8.2, S1.3 (S), S2.1, S2.2, SJ1.1, SJ2.1, SJ5.3, U1.8 (VSS), U1.EP, U2.3 (VSS), U2.EP (PWPD), U2.EP1 (PWPD), U2.EP2 (PWPD), U2.EP3 (PWPD), U2.EP4 (PWPD)
GPOUT: JP11.2, R15.1, U2.12 (GPOUT)
ILIM: R6.2, SJ4.2, U1.12 (ILIM)
ISET: R4.2, SJ3.2, U1.16 (ISET)
unnamed: R2.1, SJ1.2
unnamed: R7.1, SJ4.1
unnamed: R5.1, SJ3.1
unnamed: R12.2, S1.1 (O)
unnamed: R10.2, SJ5.2
unnamed: D1.C, R9.1
unnamed: D2.C, R10.1
OUT: C3.1, D1.A, D2.A, JP7.1, JP8.2, JP9.2, R16.1, R17.1, U1.10 (OUT), U1.11 (OUT)
SCL: JP10.4, R14.1, U2.2 (SCL)
SDA: JP10.3, R13.1, U2.1 (SDA)
SHIELD: JP1.SHIELD1 (SHIELD), JP1.SHIELD2 (SHIELD), JP1.SHIELD3 (SHIELD)
SYSOFF: JP12.1, S1.2, U1.15 (SYSOFF)
TMR: R3.2, SJ2.2, U1.14 (TMR)
TS: R1.2, R2.2, U1.1 (TS), U2.10 (BIN)
USB_ID: JP1.ID1 (USBID)
V_BATT: C2.1, R11.1, R12.1, U1.2 (BAT), U1.3 (BAT), U2.7 (SRN)
V_PU: JP10.2, R13.2, R14.2, R15.2
V_USB: C1.1, JP1.VBUS1 (VBUS), JP2.1, JP3.1, JP4.1, U1.13 (IN)

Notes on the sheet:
EN2 EN1 Current 0 0 100mA 0 1 500mA 1 0 ISET 1 1 Standby
Sets fast charge current - R_ISET range: 590-8.9k - I_CHG = ~885 / R_ISET - EX: R_ISET = 590 : I_CHG = 1.5A
Sets combined system load and battery charge currents pulled from USB input. - I_INMAX=1650 / R_ILIM - R_ILIM range: 1.1k-8k - EX: R_ILIM = 1.1k : I_INMAX = 1.5A
Supply Input
Battery Input
Supply Output
Shutoff Switch
Charge Current Select
BQ24075 - 1.5A USB-Friendly LiPo Battery Charger & Power-Path Management
I2C Pull-Ups
BQ27441-G1 Fuel Gauge
Headers
Jim Lindblom
v10
SYSOFF controls supply to the V_OUT pin. SYSOFF is active-high HIGH=OFF LOW=ON
SJ1: Cut to disable TS bypass.
SJ3: Cut to set custom ISET.
SJ4: Cut to set custom ILIM.
ILIM - System/Load Current Limit
ISET-Charge Current
TMR - Saftey Timers
Sets pre-charge and fast-charge safety timers. - Leave unconnected to set default (30min pre, 5hr charge time) - Connect to GND to disable - R_TMR range: 18k-72k - T_PRE range: 1400-2160 s - T_PRE (s) = 0.048 * R_TMR - T_MAX (s) = 10 * T_PRE
SJ2: Cut to enable charge timer.
TS - External Thermistor
- Connect TS to 10k NTC thermistor in the battery pack. - Connect a 10k resistor to GND if TS is not used.
V_PU is an externally supplied voltage to set the pull-up resistor HIGH voltage. Allowable range: 1.62-6V
Supply range: 4.35-6.4V
VDD is 1.8V generated internally
OUT is the power-path management output. It manages current supplied from the USB input to both the battery and system. Or supplies battery power to the system when USB is not connected. OUT supply w/ USB: V_USB - 0.3V OUT supply w/o USB: V_BAT - 0.05V
I2C ADDR: 0x55
SJ5 sets the operation of the power LED. To either: - Power OUT indicator - !PGOOD! indicator (Good IN supply) - Open (LED disconnected)
Battery Range: 3.3-4.2V

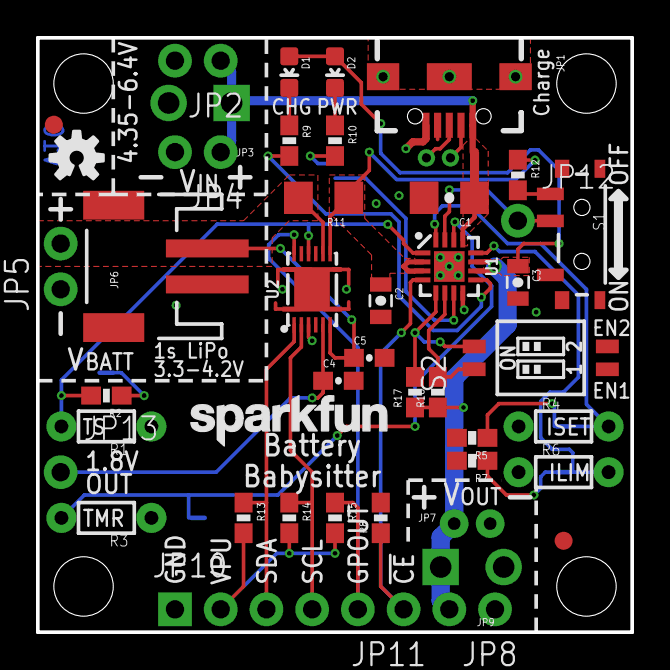
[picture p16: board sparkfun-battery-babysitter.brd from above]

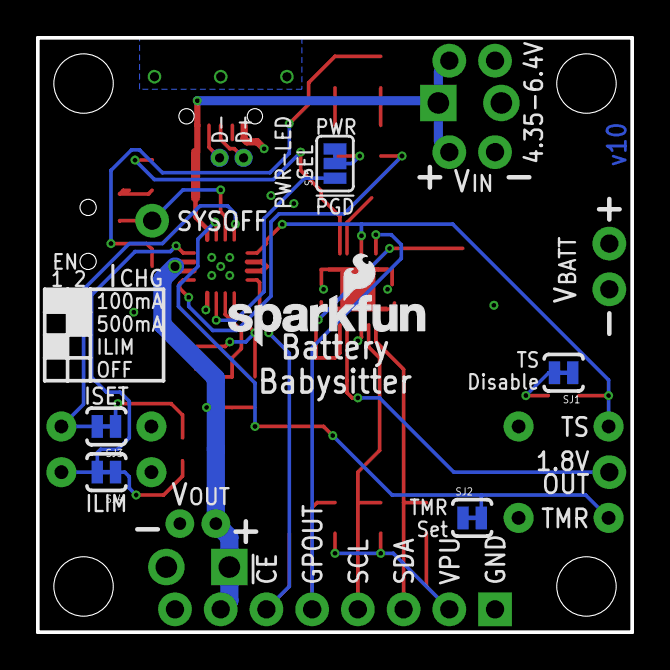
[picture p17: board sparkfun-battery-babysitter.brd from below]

Board: 2 copper layers, 33.0 x 33.0 mm, 58 parts (8 on the bottom side), 30 nets.

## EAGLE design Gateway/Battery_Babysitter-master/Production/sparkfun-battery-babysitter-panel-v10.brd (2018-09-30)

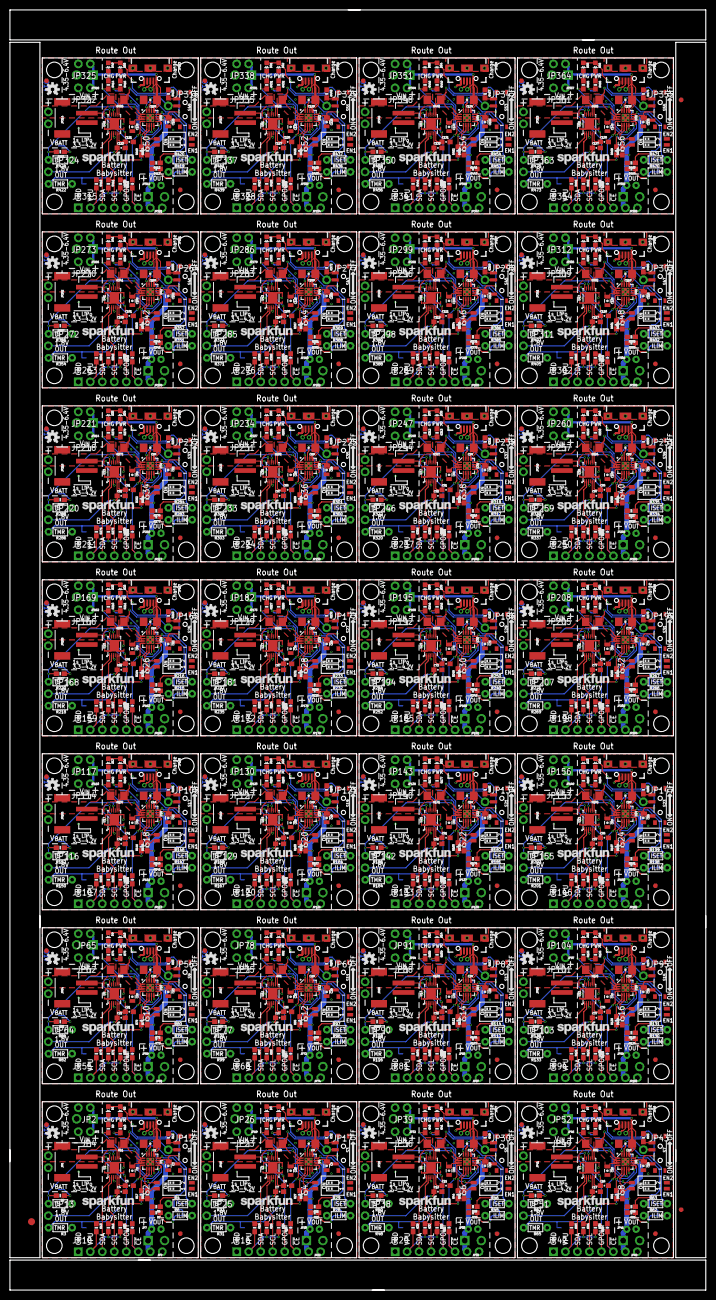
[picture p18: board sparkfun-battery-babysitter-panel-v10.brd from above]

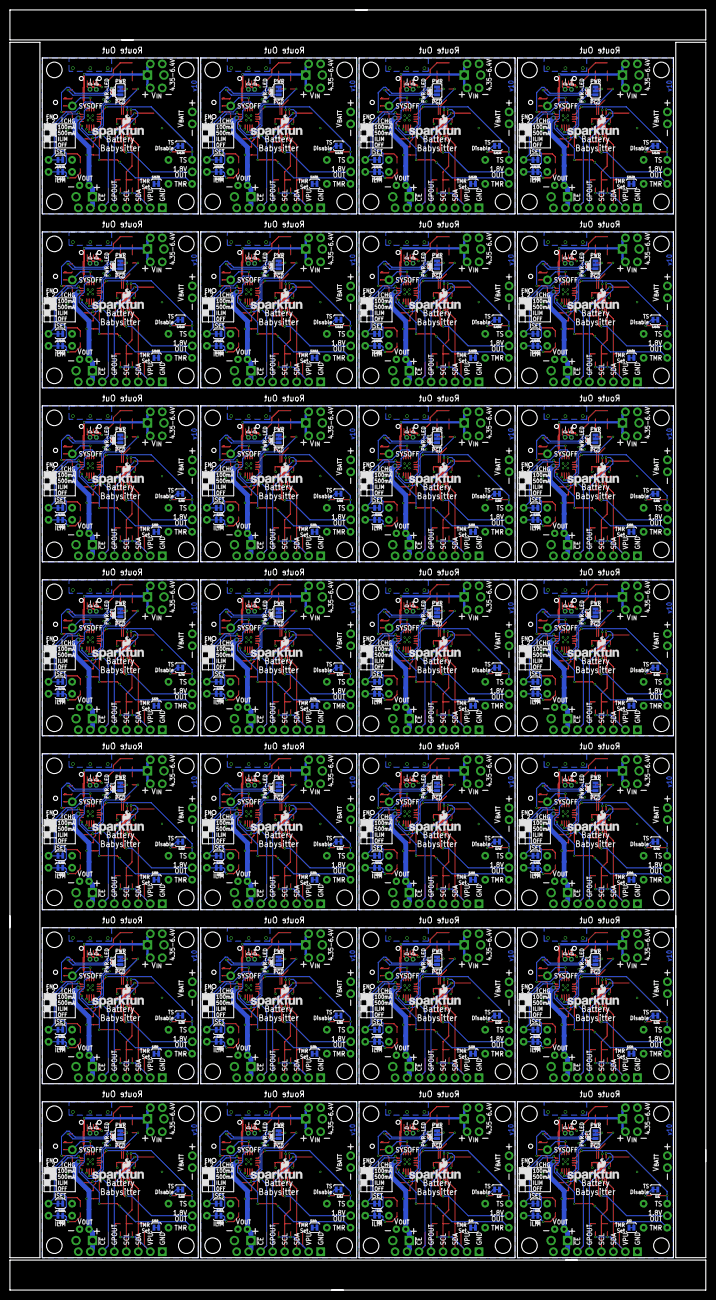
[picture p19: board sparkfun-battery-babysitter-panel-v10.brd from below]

Board: 2 copper layers, 147.3 x 271.0 mm, 1599 parts (224 on the bottom side), 840 nets.

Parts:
C1, C9, C14, C19, C24, C29, C34, C39, C44, C49, C54, C59, C64, C69, C74, C79, C84, C89, C94, C99, C104, C109, C114, C119, C124, C129, C134, C139: 1.0uF; 1206-CAP
C2, C3, C8, C10, C13, C15, C18, C20, C23, C25, C28, C30, C33, C35, C38, C40, C43, C45, C48, C50, C53, C55, C58, C60, C63, C65, C68, C70, C73, C75, C78, C80, C83, C85, C88, C90, C93, C95, C98, C100, C103, C105, C108, C110, C113, C115, C118, C120, C123, C125, C128, C130, C133, C135, C138, C140: 10uF; 0805-CAP
C4, C7, C12, C17, C22, C27, C32, C37, C42, C47, C52, C57, C62, C67, C72, C77, C82, C87, C92, C97, C102, C107, C112, C117, C122, C127, C132, C137: 0.47uF; 0603-CAP
C5, C6, C11, C16, C21, C26, C31, C36, C41, C46, C51, C56, C61, C66, C71, C76, C81, C86, C91, C96, C101, C106, C111, C116, C121, C126, C131, C136: 1.0uF; 0603-CAP
D1, D3, D5, D7, D9, D11, D13, D15, D17, D19, D21, D23, D25, D27, D29, D31, D33, D35, D37, D39, D41, D43, D45, D47, D49, D51, D53, D55: BLUE; LED-0603
D2, D4, D6, D8, D10, D12, D14, D16, D18, D20, D22, D24, D26, D28, D30, D32, D34, D36, D38, D40, D42, D44, D46, D48, D50, D52, D54, D56: RED; LED-0603
E$1: FIDUCIAL-1.5X3
E$5, E$6: FIDUCIAL-1X2
FID1, FID2, FID3, FID4, FID5, FID6, FID7, FID8, FID9, FID10, FID11, FID12, FID13, FID14, FID15, FID16, FID17, FID18, FID19, FID20, FID21, FID22, FID23, FID24, FID25, FID26, FID27, FID28, FID29, FID30, FID31, FID32, FID33, FID34, FID35, FID36, FID37, FID38, FID39, FID40, FID41, FID42, FID43, FID44, FID45, FID46, FID47, FID48, FID49, FID50, FID51, FID52, FID53, FID54, FID55, FID56: FIDUCIAL1X2; FIDUCIAL-1X2
JP1, JP14, JP27, JP40, JP53, JP66, JP79, JP92, JP105, JP118, JP131, JP144, JP157, JP170, JP183, JP196, JP209, JP222, JP235, JP248, JP261, JP274, JP287, JP300, JP313, JP326, JP339, JP352: USB-AB-MICRO-SMD_V03
JP2, JP4, JP5, JP8, JP11, JP18, JP21, JP23, JP24, JP26, JP31, JP34, JP36, JP37, JP39, JP44, JP47, JP49, JP50, JP52, JP57, JP60, JP62, JP63, JP65, JP70, JP73, JP75, JP76, JP78, JP83, JP86, JP88, JP89, JP91, JP96, JP99, JP101, JP102, JP104, JP109, JP112, JP114, JP115, JP117, JP122, JP125, JP127, JP128, JP130, JP135, JP138, JP140, JP141, JP143, JP148, JP151, JP153, JP154, JP156, JP161, JP164, JP166, JP167, JP169, JP174, JP177, JP179, JP180, JP182, JP187, JP190, JP192, JP193, JP195, JP200, JP203, JP205, JP206, JP208, JP213, JP216, JP218, JP219, JP221, JP226, JP229, JP231, JP232, JP234, JP239, JP242, JP244, JP245, JP247, JP252, JP255, JP257, JP258, JP260, JP265, JP268, JP270, JP271, JP273, JP278, JP281, JP283, JP284, JP286, JP291, JP294, JP296, JP297, JP299, JP304, JP307, JP309, JP310, JP312, JP317, JP320, JP322, JP323, JP325, JP330, JP333, JP335, JP336, JP338, JP343, JP346, JP348, JP349, JP351, JP356, JP359, JP361, JP362, JP364: 1X02_NO_SILK
JP3, JP7, JP19, JP20, JP32, JP33, JP45, JP46, JP58, JP59, JP71, JP72, JP84, JP85, JP97, JP98, JP110, JP111, JP123, JP124, JP136, JP137, JP149, JP150, JP162, JP163, JP175, JP176, JP188, JP189, JP201, JP202, JP214, JP215, JP227, JP228, JP240, JP241, JP253, JP254, JP266, JP267, JP279, JP280, JP292, JP293, JP305, JP306, JP318, JP319, JP331, JP332, JP344, JP345, JP357, JP358: SCREWTERMINAL-3.5MM-2-NS
JP6, JP15, JP28, JP41, JP54, JP67, JP80, JP93, JP106, JP119, JP132, JP145, JP158, JP171, JP184, JP197, JP210, JP223, JP236, JP249, JP262, JP275, JP288, JP301, JP314, JP327, JP340, JP353: JST-2-SMD
JP9, JP22, JP35, JP48, JP61, JP74, JP87, JP100, JP113, JP126, JP139, JP152, JP165, JP178, JP191, JP204, JP217, JP230, JP243, JP256, JP269, JP282, JP295, JP308, JP321, JP334, JP347, JP360: JST-2-PTH-NS
JP10, JP16, JP29, JP42, JP55, JP68, JP81, JP94, JP107, JP120, JP133, JP146, JP159, JP172, JP185, JP198, JP211, JP224, JP237, JP250, JP263, JP276, JP289, JP302, JP315, JP328, JP341, JP354: 1X04_NO_SILK
JP12, JP13, JP17, JP25, JP30, JP38, JP43, JP51, JP56, JP64, JP69, JP77, JP82, JP90, JP95, JP103, JP108, JP116, JP121, JP129, JP134, JP142, JP147, JP155, JP160, JP168, JP173, JP181, JP186, JP194, JP199, JP207, JP212, JP220, JP225, JP233, JP238, JP246, JP251, JP259, JP264, JP272, JP277, JP285, JP290, JP298, JP303, JP311, JP316, JP324, JP329, JP337, JP342, JP350, JP355, JP363: 1X01_NO_SILK
LOGO1, LOGO4, LOGO7, LOGO10, LOGO13, LOGO16, LOGO19, LOGO22, LOGO25, LOGO28, LOGO31, LOGO34, LOGO37, LOGO40, LOGO43, LOGO46, LOGO49, LOGO52, LOGO55, LOGO58, LOGO61, LOGO64, LOGO67, LOGO70, LOGO73, LOGO76, LOGO79, LOGO82: SFE_LOGO_NAME.1_INCH; SFE_LOGO_NAME_.1
LOGO2, LOGO6, LOGO9, LOGO12, LOGO15, LOGO18, LOGO21, LOGO24, LOGO27, LOGO30, LOGO33, LOGO36, LOGO39, LOGO42, LOGO45, LOGO48, LOGO51, LOGO54, LOGO57, LOGO60, LOGO63, LOGO66, LOGO69, LOGO72, LOGO75, LOGO78, LOGO81, LOGO84: SFE_LOGO_NAME_FLAME.1_INCH; SFE_LOGO_NAME_FLAME_.1
LOGO3, LOGO5, LOGO8, LOGO11, LOGO14, LOGO17, LOGO20, LOGO23, LOGO26, LOGO29, LOGO32, LOGO35, LOGO38, LOGO41, LOGO44, LOGO47, LOGO50, LOGO53, LOGO56, LOGO59, LOGO62, LOGO65, LOGO68, LOGO71, LOGO74, LOGO77, LOGO80, LOGO83: OSHW-LOGOS; OSHW-LOGO-S
R1, R33, R50, R67, R84, R101, R118, R135, R152, R169, R186, R203, R220, R237, R254, R271, R288, R305, R322, R339, R356, R373, R390, R407, R424, R441, R458, R475: TS; 1/6W-RES
R2, R15, R16, R17, R26, R27, R30, R34, R43, R44, R47, R51, R60, R61, R64, R68, R77, R78, R81, R85, R94, R95, R98, R102, R111, R112, R115, R119, R128, R129, R132, R136, R145, R146, R149, R153, R162, R163, R166, R170, R179, R180, R183, R187, R196, R197, R200, R204, R213, R214, R217, R221, R230, R231, R234, R238, R247, R248, R251, R255, R264, R265, R268, R272, R281, R282, R285, R289, R298, R299, R302, R306, R315, R316, R319, R323, R332, R333, R336, R340, R349, R350, R353, R357, R366, R367, R370, R374, R383, R384, R387, R391, R400, R401, R404, R408, R417, R418, R421, R425, R434, R435, R438, R442, R451, R452, R455, R459, R468, R469, R472, R476: 10K; 0603-RES
R3, R31, R48, R65, R82, R99, R116, R133, R150, R167, R184, R201, R218, R235, R252, R269, R286, R303, R320, R337, R354, R371, R388, R405, R422, R439, R456, R473: TMR; 1/6W-RES
R4, R29, R46, R63, R80, R97, R114, R131, R148, R165, R182, R199, R216, R233, R250, R267, R284, R301, R318, R335, R352, R369, R386, R403, R420, R437, R454, R471: ISET; 1/6W-RES
R5, R21, R38, R55, R72, R89, R106, R123, R140, R157, R174, R191, R208, R225, R242, R259, R276, R293, R310, R327, R344, R361, R378, R395, R412, R429, R446, R463: 590; 0603-RES
R6, R28, R45, R62, R79, R96, R113, R130, R147, R164, R181, R198, R215, R232, R249, R266, R283, R300, R317, R334, R351, R368, R385, R402, R419, R436, R453, R470: ILIM; 1/6W-RES
R7, R22, R39, R56, R73, R90, R107, R124, R141, R158, R175, R192, R209, R226, R243, R260, R277, R294, R311, R328, R345, R362, R379, R396, R413, R430, R447, R464: 1.1k; 0603-RES
R8, R12, R25, R32, R42, R49, R59, R66, R76, R83, R93, R100, R110, R117, R127, R134, R144, R151, R161, R168, R178, R185, R195, R202, R212, R219, R229, R236, R246, R253, R263, R270, R280, R287, R297, R304, R314, R321, R331, R338, R348, R355, R365, R372, R382, R389, R399, R406, R416, R423, R433, R440, R450, R457, R467, R474: 100k; 0603-RES
R9, R23, R40, R57, R74, R91, R108, R125, R142, R159, R176, R193, R210, R227, R244, R261, R278, R295, R312, R329, R346, R363, R380, R397, R414, R431, R448, R465: 180; 0603-RES
R10, R24, R41, R58, R75, R92, R109, R126, R143, R160, R177, R194, R211, R228, R245, R262, R279, R296, R313, R330, R347, R364, R381, R398, R415, R432, R449, R466: 1K; 0603-RES
R11, R18, R35, R52, R69, R86, R103, R120, R137, R154, R171, R188, R205, R222, R239, R256, R273, R290, R307, R324, R341, R358, R375, R392, R409, R426, R443, R460: 0.01; 1206
R13, R14, R19, R20, R36, R37, R53, R54, R70, R71, R87, R88, R104, R105, R121, R122, R138, R139, R155, R156, R172, R173, R189, R190, R206, R207, R223, R224, R240, R241, R257, R258, R274, R275, R291, R292, R308, R309, R325, R326, R342, R343, R359, R360, R376, R377, R393, R394, R410, R411, R427, R428, R444, R445, R461, R462: 4.7K; 0603-RES
S1, S3, S5, S7, S9, S11, S13, S15, S17, S19, S21, S23, S25, S27, S29, S31, S33, S35, S37, S39, S41, S43, S45, S47, S49, S51, S53, S55: SWITCH-SPST-SMD-A
S2, S4, S6, S8, S10, S12, S14, S16, S18, S20, S22, S24, S26, S28, S30, S32, S34, S36, S38, S40, S42, S44, S46, S48, S50, S52, S54, S56: DIPSWITCH-02-50MIL
SJ1, SJ2, SJ3, SJ4, SJ6, SJ7, SJ8, SJ9, SJ11, SJ12, SJ13, SJ14, SJ16, SJ17, SJ18, SJ19, SJ21, SJ22, SJ23, SJ24, SJ26, SJ27, SJ28, SJ29, SJ31, SJ32, SJ33, SJ34, SJ36, SJ37, SJ38, SJ39, SJ41, SJ42, SJ43, SJ44, SJ46, SJ47, SJ48, SJ49, SJ51, SJ52, SJ53, SJ54, SJ56, SJ57, SJ58, SJ59, SJ61, SJ62, SJ63, SJ64, SJ66, SJ67, SJ68, SJ69, SJ71, SJ72, SJ73, SJ74, SJ76, SJ77, SJ78, SJ79, SJ81, SJ82, SJ83, SJ84, SJ86, SJ87, SJ88, SJ89, SJ91, SJ92, SJ93, SJ94, SJ96, SJ97, SJ98, SJ99, SJ101, SJ102, SJ103, SJ104, SJ106, SJ107, SJ108, SJ109, SJ111, SJ112, SJ113, SJ114, SJ116, SJ117, SJ118, SJ119, SJ121, SJ122, SJ123, SJ124, SJ126, SJ127, SJ128, SJ129, SJ131, SJ132, SJ133, SJ134, SJ136, SJ137, SJ138, SJ139: PAD-JUMPER-2-NC_BY_TRACE_YES_SILK
SJ5, SJ10, SJ15, SJ20, SJ25, SJ30, SJ35, SJ40, SJ45, SJ50, SJ55, SJ60, SJ65, SJ70, SJ75, SJ80, SJ85, SJ90, SJ95, SJ100, SJ105, SJ110, SJ115, SJ120, SJ125, SJ130, SJ135, SJ140: PAD-JUMPER-3-2OF3_NC_BY_TRACE_YES_SILK_FULL_BOX
STANDOFF1, STANDOFF2, STANDOFF3, STANDOFF4, STANDOFF5, STANDOFF6, STANDOFF7, STANDOFF8, STANDOFF9, STANDOFF10, STANDOFF11, STANDOFF12, STANDOFF13, STANDOFF14, STANDOFF15, STANDOFF16, STANDOFF17, STANDOFF18, STANDOFF19, STANDOFF20, STANDOFF21, STANDOFF22, STANDOFF23, STANDOFF24, STANDOFF25, STANDOFF26, STANDOFF27, STANDOFF28, STANDOFF29, STANDOFF30, STANDOFF31, STANDOFF32, STANDOFF33, STANDOFF34, STANDOFF35, STANDOFF36, STANDOFF37, STANDOFF38, STANDOFF39, STANDOFF40, STANDOFF41, STANDOFF42, STANDOFF43, STANDOFF44, STANDOFF45, STANDOFF46, STANDOFF47, STANDOFF48, STANDOFF49, STANDOFF50, STANDOFF51, STANDOFF52, STANDOFF53, STANDOFF54, STANDOFF55, STANDOFF56, STANDOFF57, STANDOFF58, STANDOFF59, STANDOFF60, STANDOFF61, STANDOFF62, STANDOFF63, STANDOFF64, STANDOFF65, STANDOFF66, STANDOFF67, STANDOFF68, STANDOFF69, STANDOFF70, STANDOFF71, STANDOFF72, STANDOFF73, STANDOFF74, STANDOFF75, STANDOFF76, STANDOFF77, STANDOFF78, STANDOFF79, STANDOFF80, STANDOFF81, STANDOFF82, STANDOFF83, STANDOFF84, STANDOFF85, STANDOFF86, STANDOFF87, STANDOFF88, STANDOFF89, STANDOFF90, STANDOFF91, STANDOFF92, STANDOFF93, STANDOFF94, STANDOFF95, STANDOFF96, STANDOFF97, STANDOFF98, STANDOFF99, STANDOFF100, STANDOFF101, STANDOFF102, STANDOFF103, STANDOFF104, STANDOFF105, STANDOFF106, STANDOFF107, STANDOFF108, STANDOFF109, STANDOFF110, STANDOFF111, STANDOFF112: STAND-OFF
TP1, TP2, TP3, TP4, TP5, TP6, TP7, TP8, TP9, TP10, TP11, TP12, TP13, TP14, TP15, TP16, TP17, TP18, TP19, TP20, TP21, TP22, TP23, TP24, TP25, TP26, TP27, TP28, TP29, TP30, TP31, TP32, TP33, TP34, TP35, TP36, TP37, TP38, TP39, TP40, TP41, TP42, TP43, TP44, TP45, TP46, TP47, TP48, TP49, TP50, TP51, TP52, TP53, TP54, TP55, TP56: PAD.03X.04
U1, U4, U6, U8, U10, U12, U14, U16, U18, U20, U22, U24, U26, U28, U30, U32, U34, U36, U38, U40, U42, U44, U46, U48, U50, U52, U54, U56: BQ24075; PVQFN-N16
U2, U3, U5, U7, U9, U11, U13, U15, U17, U19, U21, U23, U25, U27, U29, U31, U33, U35, U37, U39, U41, U43, U45, U47, U49, U51, U53, U55: BQ27441-G1; PDSO-N12

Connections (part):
1.8V: C4.1, JP13.1, U2.5
1.8V1: C7.1, JP25.1, U3.5
1.8V2: C12.1, JP38.1, U5.5
1.8V3: C17.1, JP51.1, U7.5
1.8V4: C22.1, JP64.1, U9.5
1.8V5: C27.1, JP77.1, U11.5
1.8V6: C32.1, JP90.1, U13.5
1.8V7: C37.1, JP103.1, U15.5
1.8V8: C42.1, JP116.1, U17.5
1.8V9: C47.1, JP129.1, U19.5
1.8V10: C52.1, JP142.1, U21.5
1.8V11: C57.1, JP155.1, U23.5
1.8V12: C62.1, JP168.1, U25.5
1.8V13: C67.1, JP181.1, U27.5
1.8V14: C72.1, JP194.1, U29.5
1.8V15: C77.1, JP207.1, U31.5
1.8V16: C82.1, JP220.1, U33.5
1.8V17: C87.1, JP233.1, U35.5
1.8V18: C92.1, JP246.1, U37.5
1.8V19: C97.1, JP259.1, U39.5
1.8V20: C102.1, JP272.1, U41.5
1.8V21: C107.1, JP285.1, U43.5
1.8V22: C112.1, JP298.1, U45.5
1.8V23: C117.1, JP311.1, U47.5
1.8V24: C122.1, JP324.1, U49.5
1.8V25: C127.1, JP337.1, U51.5
1.8V26: C132.1, JP350.1, U53.5
1.8V27: C137.1, JP363.1, U55.5
!CE!: JP11.1, R8.1, U1.4
!CE!1: JP24.1, R25.1, U4.4
!CE!2: JP37.1, R42.1, U6.4
!CE!3: JP50.1, R59.1, U8.4
!CE!4: JP63.1, R76.1, U10.4
!CE!5: JP76.1, R93.1, U12.4
!CE!6: JP89.1, R110.1, U14.4
!CE!7: JP102.1, R127.1, U16.4
!CE!8: JP115.1, R144.1, U18.4
!CE!9: JP128.1, R161.1, U20.4
!CE!10: JP141.1, R178.1, U22.4
!CE!11: JP154.1, R195.1, U24.4
!CE!12: JP167.1, R212.1, U26.4
!CE!13: JP180.1, R229.1, U28.4
!CE!14: JP193.1, R246.1, U30.4
!CE!15: JP206.1, R263.1, U32.4
!CE!16: JP219.1, R280.1, U34.4
!CE!17: JP232.1, R297.1, U36.4
!CE!18: JP245.1, R314.1, U38.4
!CE!19: JP258.1, R331.1, U40.4
!CE!20: JP271.1, R348.1, U42.4
!CE!21: JP284.1, R365.1, U44.4
!CE!22: JP297.1, R382.1, U46.4
!CE!23: JP310.1, R399.1, U48.4
!CE!24: JP323.1, R416.1, U50.4
!CE!25: JP336.1, R433.1, U52.4
!CE!26: JP349.1, R450.1, U54.4
!CE!27: JP362.1, R467.1, U56.4
!CHG!: R9.2, U1.9
!CHG!1: R23.2, U4.9
!CHG!2: R40.2, U6.9
!CHG!3: R57.2, U8.9
!CHG!4: R74.2, U10.9
!CHG!5: R91.2, U12.9
!CHG!6: R108.2, U14.9
!CHG!7: R125.2, U16.9
!CHG!8: R142.2, U18.9
!CHG!9: R159.2, U20.9
!CHG!10: R176.2, U22.9
!CHG!11: R193.2, U24.9
!CHG!12: R210.2, U26.9
!CHG!13: R227.2, U28.9
!CHG!14: R244.2, U30.9
!CHG!15: R261.2, U32.9
!CHG!16: R278.2, U34.9
!CHG!17: R295.2, U36.9
!CHG!18: R312.2, U38.9
!CHG!19: R329.2, U40.9
!CHG!20: R346.2, U42.9
!CHG!21: R363.2, U44.9
!CHG!22: R380.2, U46.9
!CHG!23: R397.2, U48.9
!CHG!24: R414.2, U50.9
!CHG!25: R431.2, U52.9
!CHG!26: R448.2, U54.9
!CHG!27: R465.2, U56.9
!PGOOD!: SJ5.1, U1.7
!PGOOD!1: SJ10.1, U4.7
!PGOOD!2: SJ15.1, U6.7
!PGOOD!3: SJ20.1, U8.7
!PGOOD!4: SJ25.1, U10.7
!PGOOD!5: SJ30.1, U12.7
!PGOOD!6: SJ35.1, U14.7
!PGOOD!7: SJ40.1, U16.7
!PGOOD!8: SJ45.1, U18.7
!PGOOD!9: SJ50.1, U20.7
!PGOOD!10: SJ55.1, U22.7
!PGOOD!11: SJ60.1, U24.7
!PGOOD!12: SJ65.1, U26.7
!PGOOD!13: SJ70.1, U28.7
!PGOOD!14: SJ75.1, U30.7
!PGOOD!15: SJ80.1, U32.7
!PGOOD!16: SJ85.1, U34.7
!PGOOD!17: SJ90.1, U36.7
!PGOOD!18: SJ95.1, U38.7
!PGOOD!19: SJ100.1, U40.7
!PGOOD!20: SJ105.1, U42.7
!PGOOD!21: SJ110.1, U44.7
!PGOOD!22: SJ115.1, U46.7
!PGOOD!23: SJ120.1, U48.7
!PGOOD!24: SJ125.1, U50.7
!PGOOD!25: SJ130.1, U52.7
!PGOOD!26: SJ135.1, U54.7
!PGOOD!27: SJ140.1, U56.7
BATTERY_IN: C5.1, JP5.2, JP6.2, R11.2, U2.6, U2.8
BATTERY_IN1: C6.1, JP15.2, JP18.2, R18.2, U3.6, U3.8
BATTERY_IN2: C11.1, JP28.2, JP31.2, R35.2, U5.6, U5.8
BATTERY_IN3: C16.1, JP41.2, JP44.2, R52.2, U7.6, U7.8
BATTERY_IN4: C21.1, JP54.2, JP57.2, R69.2, U9.6, U9.8
BATTERY_IN5: C26.1, JP67.2, JP70.2, R86.2, U11.6, U11.8
BATTERY_IN6: C31.1, JP80.2, JP83.2, R103.2, U13.6, U13.8
BATTERY_IN7: C36.1, JP93.2, JP96.2, R120.2, U15.6, U15.8
BATTERY_IN8: C41.1, JP106.2, JP109.2, R137.2, U17.6, U17.8
BATTERY_IN9: C46.1, JP119.2, JP122.2, R154.2, U19.6, U19.8
BATTERY_IN10: C51.1, JP132.2, JP135.2, R171.2, U21.6, U21.8
BATTERY_IN11: C56.1, JP145.2, JP148.2, R188.2, U23.6, U23.8
BATTERY_IN12: C61.1, JP158.2, JP161.2, R205.2, U25.6, U25.8
BATTERY_IN13: C66.1, JP171.2, JP174.2, R222.2, U27.6, U27.8
BATTERY_IN14: C71.1, JP184.2, JP187.2, R239.2, U29.6, U29.8
BATTERY_IN15: C76.1, JP197.2, JP200.2, R256.2, U31.6, U31.8
BATTERY_IN16: C81.1, JP210.2, JP213.2, R273.2, U33.6, U33.8
BATTERY_IN17: C86.1, JP223.2, JP226.2, R290.2, U35.6, U35.8
BATTERY_IN18: C91.1, JP236.2, JP239.2, R307.2, U37.6, U37.8
BATTERY_IN19: C96.1, JP249.2, JP252.2, R324.2, U39.6, U39.8
BATTERY_IN20: C101.1, JP262.2, JP265.2, R341.2, U41.6, U41.8
BATTERY_IN21: C106.1, JP275.2, JP278.2, R358.2, U43.6, U43.8
BATTERY_IN22: C111.1, JP288.2, JP291.2, R375.2, U45.6, U45.8
BATTERY_IN23: C116.1, JP301.2, JP304.2, R392.2, U47.6, U47.8
BATTERY_IN24: C121.1, JP314.2, JP317.2, R409.2, U49.6, U49.8
BATTERY_IN25: C126.1, JP327.2, JP330.2, R426.2, U51.6, U51.8
BATTERY_IN26: C131.1, JP340.2, JP343.2, R443.2, U53.6, U53.8
BATTERY_IN27: C136.1, JP353.2, JP356.2, R460.2, U55.6, U55.8
D+: JP1.D+1, TP2.P$1
D+1: JP14.D+1, TP4.P$1
D+2: JP27.D+1, TP6.P$1
D+3: JP40.D+1, TP8.P$1
D+4: JP53.D+1, TP10.P$1
D+5: JP66.D+1, TP12.P$1
D+6: JP79.D+1, TP14.P$1
D+7: JP92.D+1, TP16.P$1
D+8: JP105.D+1, TP18.P$1
D+9: JP118.D+1, TP20.P$1
D+10: JP131.D+1, TP22.P$1
D+11: JP144.D+1, TP24.P$1
D+12: JP157.D+1, TP26.P$1
D+13: JP170.D+1, TP28.P$1
D+14: JP183.D+1, TP30.P$1
D+15: JP196.D+1, TP32.P$1
D+16: JP209.D+1, TP34.P$1
D+17: JP222.D+1, TP36.P$1
D+18: JP235.D+1, TP38.P$1
D+19: JP248.D+1, TP40.P$1
D+20: JP261.D+1, TP42.P$1
D+21: JP274.D+1, TP44.P$1
D+22: JP287.D+1, TP46.P$1
D+23: JP300.D+1, TP48.P$1
D+24: JP313.D+1, TP50.P$1
D+25: JP326.D+1, TP52.P$1
D+26: JP339.D+1, TP54.P$1
D+27: JP352.D+1, TP56.P$1
D-: JP1.D-1, TP1.P$1
D-1: JP14.D-1, TP3.P$1
D-2: JP27.D-1, TP5.P$1
D-3: JP40.D-1, TP7.P$1
D-4: JP53.D-1, TP9.P$1
D-5: JP66.D-1, TP11.P$1
D-6: JP79.D-1, TP13.P$1
D-7: JP92.D-1, TP15.P$1
D-8: JP105.D-1, TP17.P$1
D-9: JP118.D-1, TP19.P$1
D-10: JP131.D-1, TP21.P$1
D-11: JP144.D-1, TP23.P$1
D-12: JP157.D-1, TP25.P$1
D-13: JP170.D-1, TP27.P$1
D-14: JP183.D-1, TP29.P$1
D-15: JP196.D-1, TP31.P$1
D-16: JP209.D-1, TP33.P$1
D-17: JP222.D-1, TP35.P$1
D-18: JP235.D-1, TP37.P$1
D-19: JP248.D-1, TP39.P$1
D-20: JP261.D-1, TP41.P$1
D-21: JP274.D-1, TP43.P$1
D-22: JP287.D-1, TP45.P$1
D-23: JP300.D-1, TP47.P$1
D-24: JP313.D-1, TP49.P$1
D-25: JP326.D-1, TP51.P$1
D-26: JP339.D-1, TP53.P$1
D-27: JP352.D-1, TP55.P$1
EN1: R16.2, S2.4, U1.6
EN2: R17.2, S2.3, U1.5
EN3: R27.2, S4.3, U4.5
EN4: R26.2, S4.4, U4.6
EN5: R44.2, S6.3, U6.5
EN6: R43.2, S6.4, U6.6
EN7: R61.2, S8.3, U8.5
EN8: R60.2, S8.4, U8.6
EN9: R78.2, S10.3, U10.5
EN10: R77.2, S10.4, U10.6
EN11: R95.2, S12.3, U12.5
EN12: R94.2, S12.4, U12.6
EN13: R112.2, S14.3, U14.5
EN14: R111.2, S14.4, U14.6
EN15: R129.2, S16.3, U16.5
EN16: R128.2, S16.4, U16.6
EN17: R146.2, S18.3, U18.5
EN18: R145.2, S18.4, U18.6
EN19: R163.2, S20.3, U20.5
EN20: R162.2, S20.4, U20.6
EN21: R180.2, S22.3, U22.5
EN22: R179.2, S22.4, U22.6
EN23: R197.2, S24.3, U24.5
EN24: R196.2, S24.4, U24.6
EN25: R214.2, S26.3, U26.5
EN26: R213.2, S26.4, U26.6
EN27: R231.2, S28.3, U28.5
EN28: R230.2, S28.4, U28.6
EN29: R248.2, S30.3, U30.5
EN30: R247.2, S30.4, U30.6
EN31: R265.2, S32.3, U32.5
EN32: R264.2, S32.4, U32.6
EN33: R282.2, S34.3, U34.5
EN34: R281.2, S34.4, U34.6
EN35: R299.2, S36.3, U36.5
EN36: R298.2, S36.4, U36.6
EN37: R316.2, S38.3, U38.5
EN38: R315.2, S38.4, U38.6
EN39: R333.2, S40.3, U40.5
EN40: R332.2, S40.4, U40.6
EN41: R350.2, S42.3, U42.5
EN42: R349.2, S42.4, U42.6
EN43: R367.2, S44.3, U44.5
EN44: R366.2, S44.4, U44.6
EN45: R384.2, S46.3, U46.5
EN46: R383.2, S46.4, U46.6
EN47: R401.2, S48.3, U48.5
EN48: R400.2, S48.4, U48.6
EN49: R418.2, S50.3, U50.5
EN50: R417.2, S50.4, U50.6
EN51: R435.2, S52.3, U52.5
EN52: R434.2, S52.4, U52.6
EN53: R452.2, S54.3, U54.5
EN54: R451.2, S54.4, U54.6
EN55: R469.2, S56.3, U56.5
EN56: R468.2, S56.4, U56.6
GND: C1.2, C2.2, C3.2, C4.2, C5.2, JP1.GND1, JP2.2, JP3.2, JP4.2, JP5.1, JP6.1, JP7.2, JP8.1, JP9.1, JP10.1, R1.1, R3.1, R4.1, R5.2, R6.1, R7.2, R8.2, S1.3, S2.1, S2.2, SJ1.1, SJ2.1, SJ5.3, U1.8, U1.EP, U2.3, U2.EP, U2.EP1, U2.EP2, U2.EP3, U2.EP4
GND1: C6.2, C7.2, C8.2, C9.2, C10.2, JP14.GND1, JP15.1, JP16.1, JP18.1, JP19.2, JP20.2, JP21.1, JP22.1, JP23.2, JP26.2, R21.2, R22.2, R25.2, R28.1, R29.1, R31.1, R33.1, S3.3, S4.1, S4.2, SJ6.1, SJ9.1, SJ10.3, U3.3, U3.EP, U3.EP1, U3.EP2, U3.EP3, U3.EP4, U4.8, U4.EP
GND2: C11.2, C12.2, C13.2, C14.2, C15.2, JP27.GND1, JP28.1, JP29.1, JP31.1, JP32.2, JP33.2, JP34.1, JP35.1, JP36.2, JP39.2, R38.2, R39.2, R42.2, R45.1, R46.1, R48.1, R50.1, S5.3, S6.1, S6.2, SJ11.1, SJ14.1, SJ15.3, U5.3, U5.EP, U5.EP1, U5.EP2, U5.EP3, U5.EP4, U6.8, U6.EP
GND3: C16.2, C17.2, C18.2, C19.2, C20.2, JP40.GND1, JP41.1, JP42.1, JP44.1, JP45.2, JP46.2, JP47.1, JP48.1, JP49.2, JP52.2, R55.2, R56.2, R59.2, R62.1, R63.1, R65.1, R67.1, S7.3, S8.1, S8.2, SJ16.1, SJ19.1, SJ20.3, U7.3, U7.EP, U7.EP1, U7.EP2, U7.EP3, U7.EP4, U8.8, U8.EP
GND4: C21.2, C22.2, C23.2, C24.2, C25.2, JP53.GND1, JP54.1, JP55.1, JP57.1, JP58.2, JP59.2, JP60.1, JP61.1, JP62.2, JP65.2, R72.2, R73.2, R76.2, R79.1, R80.1, R82.1, R84.1, S9.3, S10.1, S10.2, SJ21.1, SJ24.1, SJ25.3, U9.3, U9.EP, U9.EP1, U9.EP2, U9.EP3, U9.EP4, U10.8, U10.EP
GND5: C26.2, C27.2, C28.2, C29.2, C30.2, JP66.GND1, JP67.1, JP68.1, JP70.1, JP71.2, JP72.2, JP73.1, JP74.1, JP75.2, JP78.2, R89.2, R90.2, R93.2, R96.1, R97.1, R99.1, R101.1, S11.3, S12.1, S12.2, SJ26.1, SJ29.1, SJ30.3, U11.3, U11.EP, U11.EP1, U11.EP2, U11.EP3, U11.EP4, U12.8, U12.EP
GND6: C31.2, C32.2, C33.2, C34.2, C35.2, JP79.GND1, JP80.1, JP81.1, JP83.1, JP84.2, JP85.2, JP86.1, JP87.1, JP88.2, JP91.2, R106.2, R107.2, R110.2, R113.1, R114.1, R116.1, R118.1, S13.3, S14.1, S14.2, SJ31.1, SJ34.1, SJ35.3, U13.3, U13.EP, U13.EP1, U13.EP2, U13.EP3, U13.EP4, U14.8, U14.EP
GND7: C36.2, C37.2, C38.2, C39.2, C40.2, JP92.GND1, JP93.1, JP94.1, JP96.1, JP97.2, JP98.2, JP99.1, JP100.1, JP101.2, JP104.2, R123.2, R124.2, R127.2, R130.1, R131.1, R133.1, R135.1, S15.3, S16.1, S16.2, SJ36.1, SJ39.1, SJ40.3, U15.3, U15.EP, U15.EP1, U15.EP2, U15.EP3, U15.EP4, U16.8, U16.EP
GND8: C41.2, C42.2, C43.2, C44.2, C45.2, JP105.GND1, JP106.1, JP107.1, JP109.1, JP110.2, JP111.2, JP112.1, JP113.1, JP114.2, JP117.2, R140.2, R141.2, R144.2, R147.1, R148.1, R150.1, R152.1, S17.3, S18.1, S18.2, SJ41.1, SJ44.1, SJ45.3, U17.3, U17.EP, U17.EP1, U17.EP2, U17.EP3, U17.EP4, U18.8, U18.EP
GND9: C46.2, C47.2, C48.2, C49.2, C50.2, JP118.GND1, JP119.1, JP120.1, JP122.1, JP123.2, JP124.2, JP125.1, JP126.1, JP127.2, JP130.2, R157.2, R158.2, R161.2, R164.1, R165.1, R167.1, R169.1, S19.3, S20.1, S20.2, SJ46.1, SJ49.1, SJ50.3, U19.3, U19.EP, U19.EP1, U19.EP2, U19.EP3, U19.EP4, U20.8, U20.EP
GND10: C51.2, C52.2, C53.2, C54.2, C55.2, JP131.GND1, JP132.1, JP133.1, JP135.1, JP136.2, JP137.2, JP138.1, JP139.1, JP140.2, JP143.2, R174.2, R175.2, R178.2, R181.1, R182.1, R184.1, R186.1, S21.3, S22.1, S22.2, SJ51.1, SJ54.1, SJ55.3, U21.3, U21.EP, U21.EP1, U21.EP2, U21.EP3, U21.EP4, U22.8, U22.EP
GND11: C56.2, C57.2, C58.2, C59.2, C60.2, JP144.GND1, JP145.1, JP146.1, JP148.1, JP149.2, JP150.2, JP151.1, JP152.1, JP153.2, JP156.2, R191.2, R192.2, R195.2, R198.1, R199.1, R201.1, R203.1, S23.3, S24.1, S24.2, SJ56.1, SJ59.1, SJ60.3, U23.3, U23.EP, U23.EP1, U23.EP2, U23.EP3, U23.EP4, U24.8, U24.EP
GND12: C61.2, C62.2, C63.2, C64.2, C65.2, JP157.GND1, JP158.1, JP159.1, JP161.1, JP162.2, JP163.2, JP164.1, JP165.1, JP166.2, JP169.2, R208.2, R209.2, R212.2, R215.1, R216.1, R218.1, R220.1, S25.3, S26.1, S26.2, SJ61.1, SJ64.1, SJ65.3, U25.3, U25.EP, U25.EP1, U25.EP2, U25.EP3, U25.EP4, U26.8, U26.EP
GND13: C66.2, C67.2, C68.2, C69.2, C70.2, JP170.GND1, JP171.1, JP172.1, JP174.1, JP175.2, JP176.2, JP177.1, JP178.1, JP179.2, JP182.2, R225.2, R226.2, R229.2, R232.1, R233.1, R235.1, R237.1, S27.3, S28.1, S28.2, SJ66.1, SJ69.1, SJ70.3, U27.3, U27.EP, U27.EP1, U27.EP2, U27.EP3, U27.EP4, U28.8, U28.EP
GND14: C71.2, C72.2, C73.2, C74.2, C75.2, JP183.GND1, JP184.1, JP185.1, JP187.1, JP188.2, JP189.2, JP190.1, JP191.1, JP192.2, JP195.2, R242.2, R243.2, R246.2, R249.1, R250.1, R252.1, R254.1, S29.3, S30.1, S30.2, SJ71.1, SJ74.1, SJ75.3, U29.3, U29.EP, U29.EP1, U29.EP2, U29.EP3, U29.EP4, U30.8, U30.EP
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

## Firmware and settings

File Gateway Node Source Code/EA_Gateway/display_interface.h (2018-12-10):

#ifndef _DISPLAY_INTERFACE_H
#define _DISPLAY_INTERFACE_H

/* radio board type ID is defined here */
#include "ble-configuration.h"

typedef void (*init_func_t)(void);
typedef void (*print_func_t)(char *str, uint8 row);

typedef struct {
  char *buff;
  int   row;
}display_interface_data_t;

typedef struct {
  init_func_t  init;
  print_func_t print;
}display_interface_t;

#if 0 && (EMBER_AF_BOARD_TYPE == BRD4104A)  \
  || (EMBER_AF_BOARD_TYPE == BRD4305A) \
  || (EMBER_AF_BOARD_TYPE == BRD4305C) \
  || (EMBER_AF_BOARD_TYPE == BRD4158A) \
  || (EMBER_AF_BOARD_TYPE == BRD4159A) \
  || (EMBER_AF_BOARD_TYPE == BRD4167A) \
  || (EMBER_AF_BOARD_TYPE == BRD4168A) \
  || (EMBER_AF_BOARD_TYPE == BRD4305D) \
  || (EMBER_AF_BOARD_TYPE == BRD4305E) \
  || (EMBER_AF_BOARD_TYPE == BRD4103A) \
  || (EMBER_AF_BOARD_TYPE == BRD4161A) \
  || (EMBER_AF_BOARD_TYPE == BRD4162A) \
  || (EMBER_AF_BOARD_TYPE == BRD4163A) \
  || (EMBER_AF_BOARD_TYPE == BRD4164A) \
  || (EMBER_AF_BOARD_TYPE == BRD4170A) \
  || (EMBER_AF_BOARD_TYPE == BRD4306A) \
  || (EMBER_AF_BOARD_TYPE == BRD4306B) \
  || (EMBER_AF_BOARD_TYPE == BRD4306C) \
  || (EMBER_AF_BOARD_TYPE == BRD4306D) \
  || (EMBER_AF_BOARD_TYPE == BRD4304A) \
  || (EMBER_AF_BOARD_TYPE == BRD4165A) \
  || (EMBER_AF_BOARD_TYPE == BRD4165B)

#include "lcd_driver.h"

#define DI_ROW_NAME         LCD_ROW_NAME
#define DI_ROW_STATUS       LCD_ROW_STATUS
#define DI_ROW_CONNECTION   LCD_ROW_CONNECTION
#define DI_ROW_FRIEND       LCD_ROW_FRIEND
#define DI_ROW_LPN          LCD_ROW_LPN
#define DI_ROW_LIGHTNESS    LCD_ROW_LIGHTNESS
#define DI_ROW_TEMPERATURE  LCD_ROW_TEMPERATURE
#define DI_ROW_DELTAUV      LCD_ROW_DELTAUV

#define DEFAULT_DISPLAY_INTERFACE \
  {                               \
    LCD_init,                     \
    LCD_write                     \
  }

#else

#define DI_ROW_NAME         0
#define DI_ROW_STATUS       0
#define DI_ROW_CONNECTION   0
#define DI_ROW_FRIEND       0
#define DI_ROW_LPN          0
#define DI_ROW_LIGHTNESS    0
#define DI_ROW_TEMPERATURE  0
#define DI_ROW_DELTAUV      0

#define DEFAULT_DISPLAY_INTERFACE \
  {                               \
    NULL,                         \
    NULL                          \
  }

#endif

void DI_Config(init_func_t init, print_func_t print);
void DI_Init(void);
void DI_Print(char *str, uint8 row);

#endif /* _DISPLAY_INTERFACE_H */

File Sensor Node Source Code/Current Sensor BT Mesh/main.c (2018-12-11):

/***********************************************************************************************//**
 * \file   main.c
 * \brief  Silicon Labs Empty Example Project
 *
 * This example demonstrates the bare minimum needed for a Blue Gecko C application
 * that allows Over-the-Air Device Firmware Upgrading (OTA DFU). The application
 * starts advertising after boot and restarts advertising after a connection is closed.
 ***************************************************************************************************
 * <b> (C) Copyright 2016 Silicon Labs, http://www.silabs.com</b>
 ***************************************************************************************************
 * This file is licensed under the Silabs License Agreement. See the file
 * "Silabs_License_Agreement.txt" for details. Before using this software for
 * any purpose, you must agree to the terms of that agreement.
 **************************************************************************************************/

/* Board headers */
#include "init_mcu.h"
#include "init_board.h"
#include "init_app.h"
#include "ble-configuration.h"
#include "board_features.h"

/* Bluetooth stack headers */
#include "bg_types.h"
#include "native_gecko.h"
#include "gatt_db.h"

/* Libraries containing default Gecko configuration values */
#include "em_emu.h"
#include "em_cmu.h"
#include "em_adc.h"

/* Device initialization header */
#include "hal-config.h"
#include "retargetserial.h"

#include "cmu.h"
#include "adc0.h"
#include "letimer.h"
#include "app_include.h"
#include "infrastructure.h"
#include "gpio.h"
#if defined(HAL_CONFIG)
#include "bsphalconfig.h"
#else
#include "bspconfig.h"
#endif

/***********************************************************************************************//**
 * @addtogroup Application
 * @{
 **************************************************************************************************/

/***********************************************************************************************//**
 * @addtogroup app
 * @{
 **************************************************************************************************/

#ifndef MAX_CONNECTIONS
#define MAX_CONNECTIONS 4
#endif
uint8_t bluetooth_stack_heap[DEFAULT_BLUETOOTH_HEAP(MAX_CONNECTIONS)];

// Gecko configuration parameters (see gecko_configuration.h)
static const gecko_configuration_t config = {
  .config_flags = 0,
  .sleep.flags = SLEEP_FLAGS_DEEP_SLEEP_ENABLE,
  .bluetooth.max_connections = MAX_CONNECTIONS,
  .bluetooth.heap = bluetooth_stack_heap,
  .bluetooth.heap_size = sizeof(bluetooth_stack_heap),
  .bluetooth.sleep_clock_accuracy = 100, // ppm
  .gattdb = &bg_gattdb_data,
  .ota.flags = 0,
  .ota.device_name_len = 3,
  .ota.device_name_ptr = "OTA",
#if (HAL_PA_ENABLE) && defined(FEATURE_PA_HIGH_POWER)
  .pa.config_enable = 1, // Enable high power PA
  .pa.input = GECKO_RADIO_PA_INPUT_VBAT, // Configure PA input to VBAT
#endif // (HAL_PA_ENABLE) && defined(FEATURE_PA_HIGH_POWER)
};

// Flag for indicating DFU Reset must be performed
uint8_t boot_to_dfu = 0;

/**
 * @brief  Main function
 */
int main(void)
{
  // Initialize device
  initMcu();
  // Initialize board
  initBoard();
  // Initialize application
  initApp();
  // Initialize stack
  gecko_init(&config);
  RETARGET_SerialInit();
  RETARGET_SerialCrLf(true);
  cmu_init();
  cmu_init_LETIMER0(1);
  gpio_init();
  // Initialize LETIMER
  letimer_init();
  // Set prescalar
  letimer_set_prescalar();
  // COMP0 and COMP1 values
  letimer_set_compvalue();
  // Setup ADC
  ADC0_setup();
  // Start ADC conversion
  ADC0_start();

  printf("Energy Auditor\n");

  while (1) {

    /* Event pointer for handling events */
    struct gecko_cmd_packet* evt;

    /* Check for stack event. */
    evt = gecko_wait_event();

    /* Handle events */
    switch (BGLIB_MSG_ID(evt->header)) {
    	  /* This event is generated when a connected client has either
    	   * 1) changed a Characteristic Client Configuration, meaning that they have enabled
    	   * or disabled Notifications or Indications, or
    	   * 2) sent a confirmation upon a successful reception of the indication. */
      case gecko_evt_gatt_server_characteristic_status_id:
    	  /* Check that the characteristic in question is temperature - its ID is defined
    	   * in gatt.xml as "temperature_measurement". Also check that status_flags = 1, meaning that
    	   * the characteristic client configuration was changed (notifications or indications
    	   * enabled or disabled). */
    	  if ((evt->data.evt_gatt_server_characteristic_status.characteristic == gattdb_current_value)
    			  && (evt->data.evt_gatt_server_characteristic_status.status_flags == 0x01)) {
    		  if (evt->data.evt_gatt_server_characteristic_status.client_config_flags == 0x02) {
    			  /* Indications have been turned ON - start the repeating timer. The 1st parameter '32768'
    			   * tells the timer to run for 1 second (32.768 kHz oscillator), the 2nd parameter is
    			   * the timer handle and the 3rd parameter '0' tells the timer to repeat continuously until
    			   * stopped manually.*/
    			  letimer_enable();
    			  //gecko_cmd_hardware_set_soft_timer(328, 0, 0);
    		  } else if (evt->data.evt_gatt_server_characteristic_status.client_config_flags == 0x00) {
    			  /* Indications have been turned OFF - stop the timer. */
    			  gecko_cmd_hardware_set_soft_timer(0, 0, 0);
    			  letimer_disable();
    		  }
    	  }
    	  break;

	  case gecko_evt_system_boot_id:
		  //gecko_bgapi_class_le_connection_init();
		  /* Set advertising parameters. 100ms advertisement interval. All channels used.
		   * The first two parameters are minimum and maximum advertising interval, both in
		   * units of (milliseconds * 1.6). The third parameter '7' sets advertising on all channels. */
		  gecko_cmd_le_gap_set_adv_parameters(BLE_ADVERTISING_MIN_COUNT,BLE_ADVERTISING_MAX_COUNT,7);
		  //gecko_cmd_le_gap_set_conn_parameters(BLE_CONNECTION_MIN_COUNT,BLE_CONNECTION_MAX_COUNT,BLE_SLAVE_LATENCY,BLE_CONNECTION_TIMEOUT_COUNT);
		  /* Start general advertising and enable connections. */
		  gecko_cmd_le_gap_set_mode(le_gap_general_discoverable, le_gap_undirected_connectable);
		  /*Set connetion parameters*/
		  gecko_cmd_le_gap_set_conn_parameters(BLE_CONNECTION_MIN_COUNT,BLE_CONNECTION_MAX_COUNT,BLE_SLAVE_LATENCY,BLE_CONNECTION_TIMEOUT_COUNT);
		break;

  	  case gecko_evt_le_connection_opened_id:
//		  letimer_enable();
  		break;

      case gecko_evt_gatt_server_user_read_request_id:
		  if(evt->data.evt_gatt_server_user_read_request.characteristic == gattdb_current_value)
		  {
			  uint8_t Buffer[2] = {0};
			  uint8_t *p = Buffer;

			  float voltage = (((float)avg_adcValue)*3.3)/4095.0;

			  uint16_t current = (voltage/330.0)*2000.0*707;

			  UINT16_TO_BITSTREAM(p, current);
			  gecko_cmd_gatt_server_send_user_read_response(
					evt->data.evt_gatt_server_user_read_request.connection, gattdb_current_value, 0, 2, Buffer);

			  avg_adcValue = 0;
		  }
    	break;

      case gecko_evt_system_external_signal_id:
      {
       	  uint8_t Buffer[2] = {0};
       	  uint8_t *p = Buffer;

//   		  printf("ADC Raw Value: %lu\n",avg_adcValue);

   		  float voltage = ((float)avg_adcValue*3.3)/4095;

//   		  printf("ADC Voltage: %f\n",voltage);

   		  uint16_t current = (voltage/330.0)*2000*707;

   		  printf("ADC Current: %d\n",current);

       	  UINT16_TO_BITSTREAM(p, current);
       	  gecko_cmd_gatt_server_send_characteristic_notification(
       	        0xFF, gattdb_current_value, 2, Buffer);

   		  avg_adcValue = 0;
      }
    	break;

//      case gecko_evt_hardware_soft_timer_id:
//      {
//    	  uint8_t Buffer[5] = {0};
//    	  uint8_t *p = Buffer;
//    	  //adcSampleValue = ADC_DataSingleGet(ADC0);
//		  printf("ADC Raw Value: %lu\n",avg_adcValue);
//
//		  float voltage = ((float)avg_adcValue*3.3)/4095;
//
//		  printf("ADC Voltage: %f\n",voltage);
//
//		  float current = (voltage/330.0)*2000;
//
//		  printf("ADC Current: %f\n",current);
//
//    	  UINT8_TO_BITSTREAM(p, 155);
//    	  UINT32_TO_BITSTREAM(p, (uint32_t)current);
//    	  gecko_cmd_gatt_server_send_characteristic_notification(
//    	        0xFF, gattdb_current_value, 5, Buffer);
//
//    	  avg_adcValue = 0;
//      }
//    	break;

      case gecko_evt_le_connection_closed_id:
    	  /*TX Power set to 0db*/
    	  //gecko_cmd_system_set_tx_power(0);
    	  /* Check if need to boot to dfu mode */
    	  if (boot_to_dfu){
    		  /* Enter to DFU OTA mode */
    		  gecko_cmd_system_reset(2);
    	  }
    	  else{
			  /* Restart advertising after client has disconnected */
			  gecko_cmd_le_gap_set_mode(le_gap_general_discoverable, le_gap_undirected_connectable);
    	  }
    	break;

      /* Events related to OTA upgrading
         ----------------------------------------------------------------------------- */

      /* Check if the user-type OTA Control Characteristic was written.
       * If ota_control was written, boot the device into Device Firmware Upgrade (DFU) mode. */
      case gecko_evt_gatt_server_user_write_request_id:
    	  if (evt->data.evt_gatt_server_user_write_request.characteristic == gattdb_ota_control){
			  /* Set flag to enter to OTA mode */
			  boot_to_dfu = 1;
			  /* Send response to Write Request */
			  gecko_cmd_gatt_server_send_user_write_response(
				evt->data.evt_gatt_server_user_write_request.connection,
				gattdb_ota_control,
				bg_err_success);

			  /* Close connection to enter to DFU OTA mode */
			  gecko_cmd_le_connection_close(evt->data.evt_gatt_server_user_write_request.connection);
    	  }
    	  else if(evt->data.evt_gatt_server_user_write_request.characteristic == gattdb_sampling_rate){
			  uint32_t samplingRateSec = *(uint32_t*)evt->data.evt_gatt_server_user_write_request.value.data;
			  gecko_cmd_hardware_set_soft_timer(32768*samplingRateSec, 0, 0);
    	  }
    	break;

      default:
        break;
    }
  }
  return 0;
}

/** @} (end addtogroup app) */
/** @} (end addtogroup Application) */

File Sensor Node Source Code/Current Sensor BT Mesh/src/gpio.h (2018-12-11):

//***********************************************************************************
// Include files
//***********************************************************************************
//#include "main.h"
#include "em_gpio.h"

//***********************************************************************************
// defined files
//***********************************************************************************

// LED0 pin is
#ifdef GATEWAY
#define	LED0_port		gpioPortB
#define LED0_pin		11
#define LED0_default	false 	// off
// LED1 pin is
#define LED1_port		gpioPortB
#define LED1_pin		13
#define LED1_default	false	// off

#else

#define	LED0_port		gpioPortF
#define LED0_pin		4
#define LED0_default	false 	// off
// LED1 pin is
#define LED1_port		gpioPortF
#define LED1_pin		5
#define LED1_default	false	// off

#endif
//***********************************************************************************
// global variables
//***********************************************************************************


//***********************************************************************************
// function prototypes
//***********************************************************************************
void gpio_init(void);

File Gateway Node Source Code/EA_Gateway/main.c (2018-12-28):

/***********************************************************************************************//**
 * \file   main.c
 * \brief  Silicon Labs Bluetooth mesh light switch example
 *
 * This example implements a Bluetooth mesh light switch.
 *
 ***************************************************************************************************
 * <b> (C) Copyright 2017 Silicon Labs, http://www.silabs.com</b>
 ***************************************************************************************************
 * This file is licensed under the Silabs License Agreement. See the file
 * "Silabs_License_Agreement.txt" for details. Before using this software for
 * any purpose, you must agree to the terms of that agreement.
 **************************************************************************************************/

/* C Standard Library headers */
#include <stdlib.h>
#include <stdio.h>

/* Board headers */
#include "init_mcu.h"
#include "init_board.h"
#include "init_app.h"
#include "ble-configuration.h"
#include "board_features.h"
#include "retargetserial.h"

/* Bluetooth stack headers */
#include "bg_types.h"
#include "native_gecko.h"
#include "gatt_db.h"
#include <gecko_configuration.h>
#include "mesh_generic_model_capi_types.h"
#include "mesh_lighting_model_capi_types.h"
#include "mesh_lib.h"
#include <mesh_sizes.h>

/* Libraries containing default Gecko configuration values */
#include "em_emu.h"
#include "em_cmu.h"
#include <em_gpio.h>
#include <em_rtcc.h>
#include <gpiointerrupt.h>

/* Device initialization header */
#include "hal-config.h"

/* Display Interface header */
#include "display_interface.h"

#if defined(HAL_CONFIG)
#include "bsphalconfig.h"
#else
#include "bspconfig.h"
#endif

#include "udelay.h"
#include "mesh_serdeser.h"

#include "SensorNodeObject.h"
#include "ncp.h"
#include "time.h"
#include "mytime.h"
#include "logger.h"

/***********************************************************************************************//**
 * @addtogroup Application
 * @{
 **************************************************************************************************/

/***********************************************************************************************//**
 * @addtogroup app
 * @{
 **************************************************************************************************/

// Maximum number of simultaneous Bluetooth connections
#define MAX_CONNECTIONS 2

// heap for Bluetooth stack
uint8_t bluetooth_stack_heap[DEFAULT_BLUETOOTH_HEAP(MAX_CONNECTIONS) + BTMESH_HEAP_SIZE + 1760];

bool mesh_bgapi_listener(struct gecko_cmd_packet *evt);

// Bluetooth advertisement set configuration
//
// At minimum the following is required:
// * One advertisement set for Bluetooth LE stack (handle number 0)
// * One advertisement set for Mesh data (handle number 1)
// * One advertisement set for Mesh unprovisioned beacons (handle number 2)
// * One advertisement set for Mesh unprovisioned URI (handle number 3)
// * N advertisement sets for Mesh GATT service advertisements
// (one for each network key, handle numbers 4 .. N+3)
//
#define MAX_ADVERTISERS (4 + MESH_CFG_MAX_NETKEYS)

// Bluetooth stack configuration
const gecko_configuration_t config =
{
  .sleep.flags = SLEEP_FLAGS_DEEP_SLEEP_ENABLE,
  .bluetooth.max_connections = MAX_CONNECTIONS,
  .bluetooth.max_advertisers = MAX_ADVERTISERS,
  .bluetooth.heap = bluetooth_stack_heap,
  .bluetooth.heap_size = sizeof(bluetooth_stack_heap) - BTMESH_HEAP_SIZE,
  .bluetooth.sleep_clock_accuracy = 100,
  .gattdb = &bg_gattdb_data,
  .btmesh_heap_size = BTMESH_HEAP_SIZE,
#if (HAL_PA_ENABLE) && defined(FEATURE_PA_HIGH_POWER)
  .pa.config_enable = 1, // Enable high power PA
  .pa.input = GECKO_RADIO_PA_INPUT_VBAT, // Configure PA input to VBAT
#endif // (HAL_PA_ENABLE) && defined(FEATURE_PA_HIGH_POWER)
  .max_timers = 16,
};

// Flag for indicating DFU Reset must be performed
uint8_t boot_to_dfu = 0;

/** Timer Frequency used. */
#define TIMER_CLK_FREQ ((uint32)32768)
/** Convert msec to timer ticks. */
#define TIMER_MS_2_TIMERTICK(ms) ((TIMER_CLK_FREQ * ms) / 1000)

#define TIMER_ID_RESTART    78
#define TIMER_ID_FACTORY_RESET  77
#define TIMER_ID_PROVISIONING   66
#define TIMER_ID_RETRANS    10
#define TIMER_ID_FRIEND_FIND 20
#define TIMER_ID_WAIT_FOR_SENSOR_NODE_RESPONSE 15
#define TIMER_ID_SENSOR_RESPONSE_TIMEOUT	19

///** Minimum color temperature 800K */
//#define TEMPERATURE_MIN      0x0320
///** Maximum color temperature 20000K */
//#define TEMPERATURE_MAX      0x4e20

/** Minimum color temperature 800K */
#define TEMPERATURE_MIN      0
/** Maximum color temperature 20000K */
#define TEMPERATURE_MAX      0xFFFF

#define DELTA_UV  0

/** global variables */
static uint16 _elem_index = 0xffff; /* For indexing elements of the node (this example has only one element) */
static uint16 _my_address = 0;    /* Address of the Primary Element of the Node */
//static uint8 switch_pos = 0;      /* current position of the switch  */
static uint8 request_count;       /* number of on/off requests to be sent */
static uint8 trid = 0;        /* transaction identifier */
static uint8 num_connections = 0;     /* number of active Bluetooth connections */
static uint8 conn_handle = 0xFF;      /* handle of the last opened LE connection */

//static uint8 lightness_percent = 0; /* lightness level percentage */
//static uint16 lightness_level = 0;  /* lightness level converted from percentage to actual value, range 0..65535*/
//static uint8 temperature_percent = 50;
//static uint16 temperature_level = 0;

/* button press timestamps for long/short press detection */
static uint32 pb0_press;
//static uint32 pb1_press;

#define LONG_PRESS_TIME_TICKS   (32768 / 4)

#define VERY_LONG_PRESS_TIME_TICKS  (1)

//gunj
bd_addr myBTAddr = {0};

/* external signal definitions. these are used to signal button press events from GPIO interrupt handler to
 * application */
#define EXT_SIGNAL_PB0_SHORT_PRESS      0x01
#define EXT_SIGNAL_PB0_LONG_PRESS       0x02
#define EXT_SIGNAL_PB1_SHORT_PRESS      0x04
#define EXT_SIGNAL_PB1_LONG_PRESS       0x08
#define EXT_SIGNAL_PB0_VERY_LONG_PRESS  0x10
#define EXT_SIGNAL_PB1_VERY_LONG_PRESS  0x20

/**
 *  State of the LEDs is updated by calling LED_set_state().
 *  The new state is passed as parameter, possible values are defined below.
 */
#define LED_STATE_OFF    0   /* light off (both LEDs turned off)   */
#define LED_STATE_ON     1   /* light on (both LEDs turned on)     */
#define LED_STATE_PROV   3   /* provisioning (LEDs blinking)       */
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

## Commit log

2018-09-29 Created PCB Project for BT Mesh
    [BT Mesh.PrjPcb]
2018-09-29 Created PCB Project for Gateway
    [Gateway.PrjPcb]
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2018-09-30 Added schematic for PMIC. Added footprints for PMIC and Regulator.
    [BGA12N40P3X4_128X202X60N.PcbLib, Gateway.PrjPcb, PMIC.PcbDoc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]
2018-10-05 Added block diagram sheet, and updated parameters in other sheets
    [BlockDiagram.SchDoc, Gateway.PrjPcb, Gecko.SchDoc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]
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2018-10-10 Initial changes to PMIC schematic according to the requirement
    [Gateway.PrjPcb, PMIC.SchDoc, PMIC_reference.SchDoc]
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2018-10-15 Updated PMIC schematic and adding libraries (SnapEDA)
    [0475901001.PcbLib, 0475901001.SchLib, AYZ0102AGRLC.PcbLib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]
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2018-10-16 Added LED parts and changed from ports to net labels
    [PMIC.SchDoc]
2018-10-16 Adding Gecko and PMU schematic
    [Gecko.SchDoc, PMIC.SchDoc, Regulator.SchDoc]
2018-10-17 Changes to PMIC and Gecko Files
    [Gecko.SchDoc, PMIC.SchDoc, PMIC_reference.SchDoc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]
2018-10-20 Modifications in Gecko.SchDoc for adding the extension header
    [Gateway.PrjPcb, Gecko.SchDoc, Regulator.SchDoc]
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2018-10-20 Updating PMIC after review
    [PMIC.SchDoc]
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2018-10-20 Update BT Mesh/Gecko IO.SchDoc
    [Gecko IO.SchDoc]
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2018-10-20 Updating component designators as per BT Mesh's nomenclature
    [Gecko.SchDoc, Gecko_IO.SchDoc, PMIC.SchDoc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]
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2018-10-21 Added ESD protection to Gateway schematics
    [430182043816.PcbLib, 430182043816.SchLib, Gecko.SchDoc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]
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2018-10-21 Updated component and sheet parameters
    [BlockDiagram.SchDoc, Gateway.PrjPcb, Gecko.SchDoc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]
2018-10-21 Patching up for component parameters
    [Gateway.PrjPcb, Gecko.SchDoc, Gecko_IO.SchDoc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]
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2018-10-21 added 100nF caps to reset circuit
    [Gecko IO.SchDoc, Gecko.SchDoc]
2018-10-22 Added FT232 for UART to USB
    New schematic sheet for FT232 for UART to USB
    updated LED designators in gateway
    [BlockDiagram.SchDoc, FT232RL-REEL.PcbLib, FT232RL-REEL.SchLib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]
2018-10-23 Added PTC, Finalized USB UART Pins
    [Gecko.SchDoc, Gecko_IO.SchDoc, PMIC.SchDoc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]
2018-10-23 Added USB UART Schematic
    [BT Mesh.xlsx, FT232RL-REEL.PcbLib, FT232RL-REEL.SchLib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]
2018-10-23 Added calculations for R_ILIM and R_ISET in PMIC.SchDoc
    [Gateway.xlsx, PMIC.SchDoc]
2018-10-23 Revision 1 for Schematic Review
    [BT Mesh.xlsx, Gecko IO.SchDoc, Gecko.SchDoc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]
2018-10-23 Grounded the open pins for Gecko
    [Gecko.SchDoc]
2018-10-23 Revision1 for Schematic Review
    [USB.SchDoc]
2018-10-26 Updated USB, Battery and Debug Connector
    [Debug_connector.PcbLib, Debug_connector.SchLib, Gecko IO.SchDoc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]
2018-10-26 Modifications to the USB supply input and Debug Interface
    [Gecko_IO.SchDoc, PMIC.SchDoc]
2018-10-26 Sensor: Updated MCU, USB UART fix
    [BGM13P22F512GA-V2.PcbLib, BGM13P22F512GA-V2.SchLib, Gecko.SchDoc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]
2018-10-26 Removed Warnings and incorporated SoC
    [BGM13P22F512GA-V2.PcbLib, BGM13P22F512GA-V2.SchLib, Gecko.SchDoc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]
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2018-10-26 Updated Component Designators to match sensor node
    [BlockDiagram.SchDoc, Gateway.PrjPcb, Gateway.xlsx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]
2018-10-27 updated digikey links for BQ24075 and BGM13P
    [Gateway.PrjPcb, Gateway.xlsx, Gecko.SchDoc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]
2018-10-27 removed note of 22uF cap
    [Regulator.SchDoc]
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2018-10-30 added footprint files and start of layout
    [1825289-1.PcbLib, 1825289-1.SchLib, 5019.PcbLib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]
2018-10-31 started layout, changed schematic symbol for PMIC
    Changed schematic for PMIC to fix issue with 2 pins shown together in schematic and that not mapping over in footprint.
    [BQ24075RGTT.PcbLib, BQ24075RGTT.SchLib, Gateway.PcbDoc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]
2018-10-31 part done layout, Attempt0-partly
    Abandoning this effort for now. Should try a different placement.
    [Gateway.PcbDoc]
2018-10-31 Layout attempt 2_ PMIC & FT232 mostly done
    UART D+, D- routing pending,
    PMIC thermal pad to be grounded
    [Gateway.PcbDoc]
2018-11-01 layout for regulator, finished PMIC and FT232.
    Starting layout for Gecko.
    [Gateway.PcbDoc, Regulator.SchDoc]
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2018-11-03 Update BT Mesh/BT Mesh.PcbDoc
    [BT Mesh.PcbDoc]
2018-11-03 fixed BOM issues in schematic
    [Gateway.PcbDoc, Gateway.PrjPcb, Gateway.xlsx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]
2018-11-03 Verified parameters of components and changed parameters of zener diodes
    [BlockDiagram.SchDoc, Gecko.SchDoc, Gecko_IO.SchDoc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]
2018-11-03 PCB Layout 1st Iteration
    [BT Mesh.PcbDoc, Gecko IO.SchDoc, Gecko.SchDoc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]
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2018-11-06 Sensor Node PCB Layout Revision1
    [BT Mesh.PcbDoc, Gecko IO.SchDoc, PMIC.SchDoc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]
2018-11-06 Snesor Node Layout Rev1
    [BT Mesh.PcbDoc, Gecko IO.SchDoc, Regulator.SchDoc]
2018-11-06 Sensor Node Layout Rev1
    [BT Mesh.PcbDoc, Regulator.SchDoc]
2018-11-07 Schematic with parts order list
    [Gateway.xlsx, Gecko_IO.SchDoc, PMIC.SchDoc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]
2018-11-08 Sensor Node Layout Rev1.1
    [BT Mesh.PcbDoc, BT Mesh.PrjPcb, Gecko.SchDoc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]
2018-11-08 Basic layout done. to be reviewed. Changed schematic to ease layout. Positions of IO pins on gecko.
    [Debug_connector.PcbLib, Gateway.PcbDoc, Gecko.SchDoc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]
2018-11-08 Layout without any traces on bottom ground layer. To add 2 0ohm resistors on top layer.
    [Gateway.PcbDoc]
2018-11-08 Completed layout first pass.
    [Gateway.PcbDoc, Gecko.SchDoc, Gecko_IO.SchDoc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]
2018-11-11 Updated Switch 5 Text Box
    [Gecko.SchDoc]
2018-11-13 Layout done. To move to accommodate ground plane.
    [BlockDiagram.SchDoc, Gateway.PcbDoc, Gecko.SchDoc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]
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2018-11-13 Made the changes according to antenna power specification
    [Gateway.PcbDoc]
2018-11-13 Added polarity for Diodes and LEDs
    [Gateway.PcbDoc]
2018-11-13 Added polarity to Diodes and LEDs
    [Gateway.PcbDoc]
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2018-11-14 Final PCB Layout-Sensor Node
    [BT Mesh.DRL, BT Mesh.GBL, BT Mesh.GBO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]
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2018-12-15 Minor bug fix: letimer.c
    [letimer.c, main.c]
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2018-12-16 Error handling to avoid Block and attaching self healing to it
    [main.c, ncp.c, ncp_uart.c]
2018-12-16 adding Single point of failure template call
    [main.c]
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

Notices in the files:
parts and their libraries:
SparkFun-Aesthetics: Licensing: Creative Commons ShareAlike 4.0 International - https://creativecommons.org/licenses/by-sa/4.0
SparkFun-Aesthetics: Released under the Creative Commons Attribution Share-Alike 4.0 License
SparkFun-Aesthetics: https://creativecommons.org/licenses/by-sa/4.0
